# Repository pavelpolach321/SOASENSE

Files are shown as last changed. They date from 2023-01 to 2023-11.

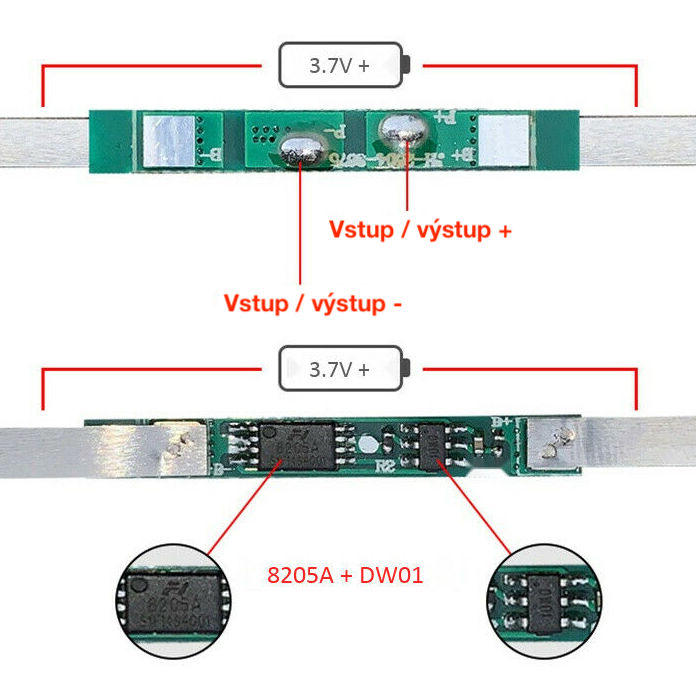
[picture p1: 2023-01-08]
Docs/bms-1s-3A-detail.jpg

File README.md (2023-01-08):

# About this repository:

The code is in the src/ folder

Mode of operation can be controlled with microswitches on the top board.

position  function           LEFT                     RIGHT     Comment
[8]       wifi credentials   setup or use old setup   erase     Implemented
[7]       connectivity       wifi                     lorawan   Not implemented yet
[6]       display            on                       off       Not implemented yet
[5]       reserved           [x]                      [x]       Not implemented yet
[4]       serial debug       on                       off       Not implemented yet
[3]       serial output      text                     json      Not implemented yet
[2]       reserved           [x]                      [x]       Not implemented yet
[1]       reserved           [x]                      [x]       Not implemented yet

# Connect the node

* Toggle the on/off switch down.
* Connect the power cable
* To erase/reset wifi credentials, put the swqitch n.8 to the right
* Toggle the on/off switch up, the board will start and display will show MAC address and AP details. Previously saved wifi cponnection is erased. Node is ready to connect.
* Put the switch n.8 to the left and reset/re-power the node
* Check accessible AP points with your mobile, search for SOASENSE_AP
* Connect with password "tacrnode"
* Page should appear, if not, gGo to 192.168.0.4, setup wifi credentials where you want node to be conected
* Node will restart itself and start sending data. You can see counter and other details on display.

# Firmware files

For provisioning use files in node_setup/ and keyfiles/ folders

During normal fw compilation, EEPROM mode should be "#define EEPROM_MODE         EEPROM_SHOW"

All sensor's related files are in a folder src/hardware'

To disable/enable/control sensor's behaviour', check setup.h file.

Most of the functional code of LMIC-node stays the same, we just introduced a few function calls to collect data, create payload and write results into debug. Function related to our fork are in hardware.cpp/.h

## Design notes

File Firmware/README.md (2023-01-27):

Currently, WIFI is used as a wireless protocol for transferring data.

Operating manual could be found here: https://github.com/pavelpolach321/SOASENSE/blob/master/README.md

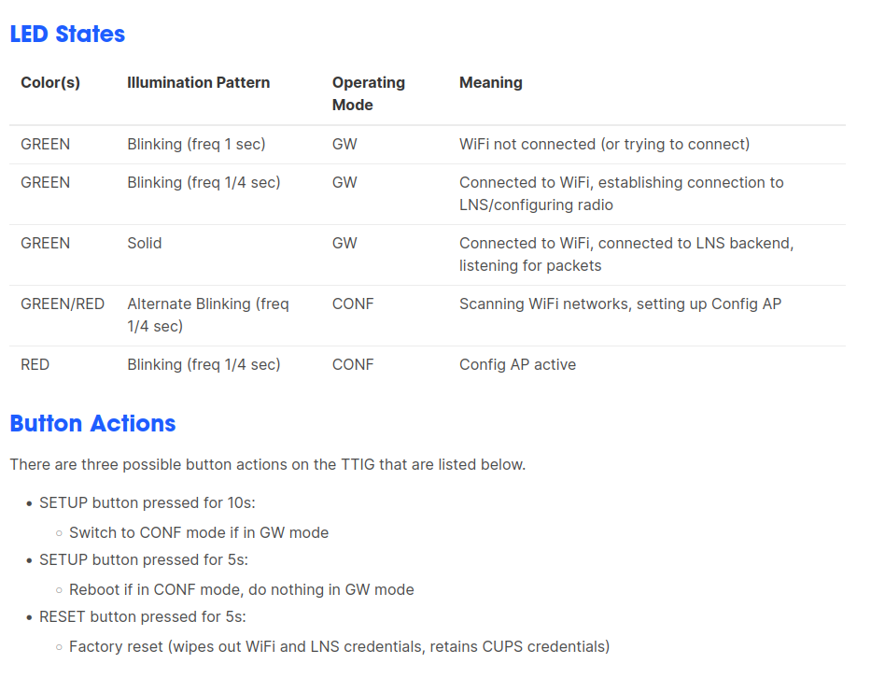
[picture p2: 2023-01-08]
Docs/gateway.png

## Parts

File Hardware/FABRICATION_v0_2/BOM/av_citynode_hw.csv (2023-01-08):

Id | Designator | Package | Quantity | Designation | Supplier and ref
1 | R9,R11,R7,R8,R6 | R_0805_2012Metric | 5 | 100k
2 | H9,H5,H3,H4,H1,H2,H6 | MountingHole_4.3mm_M4 | 7 | MountingHole
3 | R17 | R_0805_2012Metric | 1 | R
4 | J10,J11,J1,J3,J17,J22,J7,J19,J2,J12,J24,J16,J18,J21,J6,J23,J14,J5,J9,J15 | PinSocket_1x10_P2.54mm_Vertical | 20 | Conn_01x10_Female
5 | U7 | SOIC-16_4.55x10.3mm_P1.27mm | 1 | PCF8574
6 | J4 | PinSocket_1x02_P2.54mm_Vertical | 1 | Batt_wire
7 | U13 | SPS30 | 1 | SPS30
8 | U6 | PPAK | 1 | 59151
9 | C4,C1,C24,C8 | C_0805_2012Metric_Pad1.18x1.45mm_HandSolder | 4 | 100n
10 | C13,C11 | C_0805_2012Metric | 2 | 22u
11 | R13,R14,R4,R5,R1,R2,R15,R12,R16,R3 | R_0805_2012Metric | 10 | 10k
12 | J28,J27 | PinSocket_1x01_P2.54mm_Vertical | 2 | Conn_01x01_Female
13 | R10 | R_0805_2012Metric | 1 | 220k
14 | C3 | C_0805_2012Metric_Pad1.18x1.45mm_HandSolder | 1 | 1uF
15 | U9 | LILYGO-LORAWAN | 1 | LILYGO-lorawan
16 | U5 | STEP_UP | 1 | DC-DC
17 | H8,H7 | opc-n3-hole | 2 | MountingHole
18 | C19,C7,C21,C17 | C_0805_2012Metric | 4 | 10n
19 | C12,C22,C10,C18,C16,C14 | C_0805_2012Metric | 6 | 100n
20 | JP8,JP18,JP17,JP9 | SolderJumper-3_P1.3mm_Bridged12_Pad1.0x1.5mm | 4 | SolderJumper_3_Bridged12
21 | JP6,JP5,JP10,JP12,JP4,JP7,JP15 | SolderJumper-2_P1.3mm_Bridged_RoundedPad1.0x1.5mm | 7 | Close
22 | U20,U3,U2,U1 | Sensor_module | 4 | Sensor_socket
23 | U4 | DC-DC | 1 | MPPT
24 | C5,C20 | CP_Radial_D5.0mm_P2.50mm | 2 | 220u
25 | SW3 | SW_PUSH_6mm | 1 | SW_DIP_x01
26 | JP11 | SolderJumper-2_P1.3mm_Bridged_RoundedPad1.0x1.5mm | 1 | SolderJumper_2_Open
27 | SW1 | SW_DIP_SPSTx08_Slide_6.7x21.88mm_W7.62mm_P2.54mm_LowProfile | 1 | SW_DIP_x08
28 | U22 | SOT-223 | 1 | TC1264-3v3
29 | C26,C9,C6,C2 | C_0805_2012Metric_Pad1.18x1.45mm_HandSolder | 4 | dnp
30 | BT1,BT2 | BatteryHolder_MPD_BH-18650-PC2 | 2 | Battery_Cell
31 | JP1 | SolderJumper-3_P1.3mm_Bridged12_RoundedPad1.0x1.5mm_NumberLabels | 1 | SolderJumper_3_Bridged12
32 | J26 | PinHeader_1x01_P2.54mm_Vertical | 1 | Conn_01x01_Female
33 | SW2 | Switch | 1 | SW_DPDT_x2
34 | U14 | NEO-6M-mod | 1 | NEO-6M
35 | J25 | PinSocket_1x04_P2.54mm_Vertical | 1 | Conn_01x04_Female
36 | U15 | SOT-223 | 1 | XC6203P352FR-G_
37 | JP3 | SolderJumper-2_P1.3mm_Bridged_Pad1.0x1.5mm | 1 | Close
38 | J8 | BarrelJack_Horizontal | 1 | Barrel_Jack_Switch
39 | JP2 | SolderJumper-2_P1.3mm_Open_RoundedPad1.0x1.5mm | 1 | SolderJumper_2_Open
40 | U23,U25,U24 | mp2315-module | 3 | step-down
41 | AFE3,AFE1,AFE4 | Alphasense_AFE_6pin-LEFT | 3 | Alphasense_AFE_6pin
42 | C15 | CP_Radial_D10.0mm_P3.50mm | 1 | 470u
43 | J13 | PinHeader_1x05_P2.54mm_Vertical | 1 | Conn_01x05_Female
44 | U12 | opc-n3_3holes | 1 | OPC_N3
45 | AFE2 | Alphasense_AFE_6pin-RIGHT | 1 | Alphasense_AFE_6pin
46 | U11,U8 | ADS1115-module | 2 | ADS1115_module
47 | JP16 | SolderJumper-2_P1.3mm_Bridged_RoundedPad1.0x1.5mm | 1 | close
48 | U21,U19 | DW01_protection | 2 | DW01_protection
49 | JP13,JP14 | SolderJumper-2_P1.3mm_Open_RoundedPad1.0x1.5mm | 2 | Open
50 | C23 | CP_Radial_D12.5mm_P5.00mm | 1 | 2200uF
51 | U10 | BME280-module | 1 | BME280_module
52 | J20 | PinHeader_1x06_P2.54mm_Vertical | 1 | Conn_01x06_Female

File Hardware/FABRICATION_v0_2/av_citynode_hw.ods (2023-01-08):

Id | Designator | Package | Quantity | Designation | Supplier and ref
1 | R9,R11,R7,R8,R6 | R_0805_2012Metric | 5 | 100k
2 | H9,H5,H3,H4,H1,H2,H6 | MountingHole_4.3mm_M4 | 7 | MountingHole
3 | R17 | R_0805_2012Metric | 1 | R
4 | J10,J11,J1,J3,J17,J22,J7,J19,J2,J12,J24,J16,J18,J21,J6,J23,J14,J5,J9,J15 | PinSocket_1x10_P2.54mm_Vertical | 20 | Conn_01x10_Female
5 | U7 | SOIC-16_4.55x10.3mm_P1.27mm | 1 | PCF8574 | https://cz.mouser.com/ProductDetail/NXP-Semiconductors/PCF8574T-3518?qs=LOCUfHb8d9srwcgHHpXqQw%3D%3D
6 | J4 | PinSocket_1x02_P2.54mm_Vertical | 1 | Batt_wire
7 | U13 | SPS30 | 1 | SPS30
8 | U6 | PPAK | 1 | 59151
9 | C4,C1,C24,C8 | C_0805_2012Metric_Pad1.18x1.45mm_HandSolder | 4 | 100n
10 | C13,C11 | C_0805_2012Metric | 2 | 22u
11 | R13,R14,R4,R5,R1,R2,R15,R12,R16,R3 | R_0805_2012Metric | 10 | 10k
12 | J28,J27 | PinSocket_1x01_P2.54mm_Vertical | 2 | Conn_01x01_Female
13 | R10 | R_0805_2012Metric | 1 | 220k
14 | C3 | C_0805_2012Metric_Pad1.18x1.45mm_HandSolder | 1 | 1uF
15 | U9 | LILYGO-LORAWAN | 1 | LILYGO-lorawan
16 | U5 | STEP_UP | 1 | DC-DC
17 | H8,H7 | opc-n3-hole | 2 | MountingHole
18 | C19,C7,C21,C17 | C_0805_2012Metric | 4 | 10n
19 | C12,C22,C10,C18,C16,C14 | C_0805_2012Metric | 6 | 100n
20 | JP8,JP18,JP17,JP9 | SolderJumper-3_P1.3mm_Bridged12_Pad1.0x1.5mm | 4 | SolderJumper_3_Bridged12
21 | JP6,JP5,JP10,JP12,JP4,JP7,JP15 | SolderJumper-2_P1.3mm_Bridged_RoundedPad1.0x1.5mm | 7 | Close
22 | U20,U3,U2,U1 | Sensor_module | 4 | Sensor_socket
23 | U4 | DC-DC | 1 | MPPT
24 | C5,C20 | CP_Radial_D5.0mm_P2.50mm | 2 | 220u
25 | SW3 | SW_PUSH_6mm | 1 | SW_DIP_x01 | https://www.gme.cz/tc-0109
26 | JP11 | SolderJumper-2_P1.3mm_Bridged_RoundedPad1.0x1.5mm | 1 | SolderJumper_2_Open
27 | SW1 | SW_DIP_SPSTx08_Slide_6.7x21.88mm_W7.62mm_P2.54mm_LowProfile | 1 | SW_DIP_x08 | https://cz.mouser.com/ProductDetail/Diptronics/NDI-08S-V?qs=MLItCLRbWszcDzTw3vqmsQ%3D%3D
28 | U22 | SOT-223 | 1 | TC1264-3v3 | https://cz.mouser.com/ProductDetail/Microchip-Technology-Atmel/TC1264-3.3VDBTR?qs=EkZBwCRGcSs72PT5fOeaFg%3D%3D
29 | C26,C9,C6,C2 | C_0805_2012Metric_Pad1.18x1.45mm_HandSolder | 4 | dnp
30 | BT1,BT2 | BatteryHolder_MPD_BH-18650-PC2 | 2 | Battery_Cell
31 | JP1 | SolderJumper-3_P1.3mm_Bridged12_RoundedPad1.0x1.5mm_NumberLabels | 1 | SolderJumper_3_Bridged12
32 | J26 | PinHeader_1x01_P2.54mm_Vertical | 1 | Conn_01x01_Female
33 | SW2 | Switch | 1 | SW_DPDT_x2 | https://www.gme.cz/p-knx2
34 | U14 | NEO-6M-mod | 1 | NEO-6M
35 | J25 | PinSocket_1x04_P2.54mm_Vertical | 1 | Conn_01x04_Female
36 | U15 | SOT-223 | 1 | XC6203P352FR-G_
37 | JP3 | SolderJumper-2_P1.3mm_Bridged_Pad1.0x1.5mm | 1 | Close
38 | J8 | BarrelJack_Horizontal | 1 | Barrel_Jack_Switch
39 | JP2 | SolderJumper-2_P1.3mm_Open_RoundedPad1.0x1.5mm | 1 | SolderJumper_2_Open
40 | U23,U25,U24 | mp2315-module | 3 | step-down | https://www.laskakit.cz/mikro-step-down-menic--nastavitelny/
41 | AFE3,AFE1,AFE4 | Alphasense_AFE_6pin-LEFT | 3 | Alphasense_AFE_6pin
42 | C15 | CP_Radial_D10.0mm_P3.50mm | 1 | 470u
43 | J13 | PinHeader_1x05_P2.54mm_Vertical | 1 | Conn_01x05_Female
44 | U12 | opc-n3_3holes | 1 | OPC_N3
45 | AFE2 | Alphasense_AFE_6pin-RIGHT | 1 | Alphasense_AFE_6pin
46 | U11,U8 | ADS1115-module | 2 | ADS1115_module
47 | JP16 | SolderJumper-2_P1.3mm_Bridged_RoundedPad1.0x1.5mm | 1 | close
48 | U21,U19 | DW01_protection | 2 | DW01_protection
49 | JP13,JP14 | SolderJumper-2_P1.3mm_Open_RoundedPad1.0x1.5mm | 2 | Open
50 | U10 | BME280-module | 1 | BME280_module
51 | J20 | PinHeader_1x06_P2.54mm_Vertical | 1 | Conn_01x06_Female
 | baterka |  |  |  | https://www.gme.cz/oloveny-akumulator-westinghouse-wa650-6v-5ah
 | adapter |  |  |  | https://www.gme.cz/napajeci-adapter-sitovy-9v-600ma-5-5-2-1mm-vigan
 | levnejsi board |  |  |  | https://www.laskakit.cz/mh-et-live-esp32-minikit--wemos-d1-mini-shield-kompatibilni/

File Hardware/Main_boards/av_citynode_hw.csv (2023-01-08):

Source: | /home/ia/Desktop/node/av_citynode_hw/av_citynode_hw.kicad_sch
Date: | Wed 26 Oct 2022 01:55:53 PM CEST
Tool: | Eeschema 6.0.7-f9a2dced07~116~ubuntu20.04.1
Generator: | /usr/share/kicad/plugins/bom_csv_grouped_by_value.py
Component Count: | 111
Individual Components:
Item | Qty | Reference(s) | Value | LibPart | Footprint | Datasheet
 |  | AFE1 | Alphasense_AFE_6pin | city_node:Alphasense_AFE_6pin | city_node_footprints:Alphasense_AFE_6pin-LEFT
 |  | AFE2 | Alphasense_AFE_6pin | city_node:Alphasense_AFE_6pin | city_node_footprints:Alphasense_AFE_6pin-RIGHT
 |  | BT1 | Battery_Cell | Device:Battery_Cell | Battery:BatteryHolder_MPD_BH-18650-PC2 | ~
 |  | BT2 | Battery_Cell | Device:Battery_Cell | Battery:BatteryHolder_MPD_BH-18650-PC2 | ~
 |  | C1 | C | Device:C | Capacitor_SMD:C_0805_2012Metric_Pad1.18x1.45mm_HandSolder | ~
 |  | C2 | C | Device:C | Capacitor_SMD:C_0805_2012Metric_Pad1.18x1.45mm_HandSolder | ~
 |  | C3 | 10n | Device:C | Capacitor_SMD:C_0805_2012Metric_Pad1.18x1.45mm_HandSolder | ~
 |  | C4 | C | Device:C | Capacitor_SMD:C_0805_2012Metric_Pad1.18x1.45mm_HandSolder | ~
 |  | C5 | 10n | Device:C | Capacitor_SMD:C_0805_2012Metric_Pad1.18x1.45mm_HandSolder | ~
 |  | C6 | C | Device:C | Capacitor_SMD:C_0805_2012Metric_Pad1.18x1.45mm_HandSolder | ~
 |  | C7 | 10n | Device:C | Capacitor_SMD:C_0805_2012Metric_Pad1.18x1.45mm_HandSolder | ~
 |  | C8 | C | Device:C | Capacitor_SMD:C_0805_2012Metric_Pad1.18x1.45mm_HandSolder | ~
 |  | C9 | C | Device:C | Capacitor_SMD:C_0805_2012Metric_Pad1.18x1.45mm_HandSolder | ~
 |  | C10 | C | Device:C | Capacitor_SMD:C_0805_2012Metric | ~
 |  | C11 | C | Device:C | Capacitor_SMD:C_0805_2012Metric | ~
 |  | C12 | C | Device:C | Capacitor_SMD:C_0805_2012Metric | ~
 |  | C13 | C | Device:C | Capacitor_SMD:C_0805_2012Metric | ~
 |  | C14 | 100n | Device:C | Capacitor_SMD:C_0805_2012Metric | ~
 |  | C15 | 470u | Device:C | Capacitor_THT:CP_Radial_D10.0mm_P3.50mm | ~
 |  | C16 | 100n | Device:C | Capacitor_SMD:C_0805_2012Metric | ~
 |  | C17 | 10n | Device:C | Capacitor_SMD:C_0805_2012Metric | ~
 |  | C18 | 100n | Device:C | Capacitor_SMD:C_0805_2012Metric | ~
 |  | C19 | 22u | Device:C | Capacitor_SMD:C_0805_2012Metric | ~
 |  | C20 | 470u | Device:C | Capacitor_THT:CP_Radial_D5.0mm_P2.50mm | ~
 |  | C21 | 10n | Device:C | Capacitor_SMD:C_0805_2012Metric | ~
 |  | C22 | 10n | Device:C | Capacitor_SMD:C_0805_2012Metric | ~
 |  | C23 | C | Device:C | Capacitor_SMD:C_0805_2012Metric_Pad1.18x1.45mm_HandSolder | ~
 |  | C24 | C | Device:C | Capacitor_SMD:C_0805_2012Metric_Pad1.18x1.45mm_HandSolder | ~
 |  | C25 | C | Device:C | Capacitor_SMD:C_0805_2012Metric_Pad1.18x1.45mm_HandSolder | ~
 |  | C26 | C | Device:C | Capacitor_SMD:C_0805_2012Metric_Pad1.18x1.45mm_HandSolder | ~
 |  | H1 | MountingHole | Mechanical:MountingHole | city_node_footprints:MountingHole_4.3mm_M4 | ~
 |  | H2 | MountingHole | Mechanical:MountingHole | city_node_footprints:MountingHole_4.3mm_M4 | ~
 |  | H3 | MountingHole | Mechanical:MountingHole | city_node_footprints:MountingHole_4.3mm_M4 | ~
 |  | H4 | MountingHole | Mechanical:MountingHole | city_node_footprints:MountingHole_4.3mm_M4 | ~
 |  | H5 | MountingHole | Mechanical:MountingHole | city_node_footprints:MountingHole_4.3mm_M4 | ~
 |  | H6 | MountingHole | Mechanical:MountingHole | city_node_footprints:MountingHole_4.3mm_M4 | ~
 |  | H7 | MountingHole | Mechanical:MountingHole | city_node_footprints:opc-n3-hole | ~
 |  | H8 | MountingHole | Mechanical:MountingHole | city_node_footprints:opc-n3-hole | ~
 |  | J1 | Conn_01x10_Female | Connector:Conn_01x10_Female | Connector_PinSocket_2.54mm:PinSocket_1x10_P2.54mm_Vertical | ~
 |  | J2 | Conn_01x10_Female | Connector:Conn_01x10_Female | Connector_PinSocket_2.54mm:PinSocket_1x10_P2.54mm_Vertical | ~
 |  | J3 | Conn_01x10_Female | Connector:Conn_01x10_Female | Connector_PinSocket_2.54mm:PinSocket_1x10_P2.54mm_Vertical | ~
 |  | J4 | Batt_wire | Connector:Conn_01x02_Female | Connector_PinSocket_2.54mm:PinSocket_1x02_P2.54mm_Vertical | ~
 |  | J5 | Conn_01x10_Female | Connector:Conn_01x10_Female | Connector_PinSocket_2.54mm:PinSocket_1x10_P2.54mm_Vertical | ~
 |  | J6 | Conn_01x10_Female | Connector:Conn_01x10_Female | Connector_PinSocket_2.54mm:PinSocket_1x10_P2.54mm_Vertical | ~
 |  | J7 | Conn_01x10_Female | Connector:Conn_01x10_Female | Connector_PinSocket_2.54mm:PinSocket_1x10_P2.54mm_Vertical | ~
 |  | J8 | Barrel_Jack_Switch | Connector:Barrel_Jack_Switch | Connector_BarrelJack:BarrelJack_Horizontal | ~
 |  | J9 | Conn_01x10_Female | Connector:Conn_01x10_Female | Connector_PinSocket_2.54mm:PinSocket_1x10_P2.54mm_Vertical | ~
 |  | J10 | Conn_01x10_Female | Connector:Conn_01x10_Female | Connector_PinSocket_2.54mm:PinSocket_1x10_P2.54mm_Vertical | ~
 |  | J11 | Conn_01x10_Female | Connector:Conn_01x10_Female | Connector_PinSocket_2.54mm:PinSocket_1x10_P2.54mm_Vertical | ~
 |  | J12 | Conn_01x10_Female | Connector:Conn_01x10_Female | Connector_PinSocket_2.54mm:PinSocket_1x10_P2.54mm_Vertical | ~
 |  | J13 | Conn_01x05_Female | Connector:Conn_01x05_Female | Connector_PinHeader_2.54mm:PinHeader_1x05_P2.54mm_Vertical | ~
 |  | J14 | Conn_01x10_Female | Connector:Conn_01x10_Female | Connector_PinSocket_2.54mm:PinSocket_1x10_P2.54mm_Vertical | ~
 |  | J15 | Conn_01x10_Female | Connector:Conn_01x10_Female | Connector_PinSocket_2.54mm:PinSocket_1x10_P2.54mm_Vertical | ~
 |  | J16 | Conn_01x10_Female | Connector:Conn_01x10_Female | Connector_PinSocket_2.54mm:PinSocket_1x10_P2.54mm_Vertical | ~
 |  | J17 | Conn_01x10_Female | Connector:Conn_01x10_Female | Connector_PinSocket_2.54mm:PinSocket_1x10_P2.54mm_Vertical | ~
 |  | J18 | Conn_01x10_Female | Connector:Conn_01x10_Female | Connector_PinSocket_2.54mm:PinSocket_1x10_P2.54mm_Vertical | ~
 |  | J19 | Conn_01x10_Female | Connector:Conn_01x10_Female | Connector_PinSocket_2.54mm:PinSocket_1x10_P2.54mm_Vertical | ~
 |  | J20 | Conn_01x06_Female | Connector:Conn_01x06_Female | Connector_PinHeader_2.54mm:PinHeader_1x06_P2.54mm_Vertical | ~
 |  | J21 | Conn_01x10_Female | Connector:Conn_01x10_Female | Connector_PinSocket_2.54mm:PinSocket_1x10_P2.54mm_Vertical | ~
 |  | J22 | Conn_01x10_Female | Connector:Conn_01x10_Female | Connector_PinSocket_2.54mm:PinSocket_1x10_P2.54mm_Vertical | ~
 |  | J23 | Conn_01x10_Female | Connector:Conn_01x10_Female | Connector_PinSocket_2.54mm:PinSocket_1x10_P2.54mm_Vertical | ~
 |  | J24 | Conn_01x10_Female | Connector:Conn_01x10_Female | Connector_PinSocket_2.54mm:PinSocket_1x10_P2.54mm_Vertical | ~
 |  | J25 | Conn_01x04_Female | Connector:Conn_01x04_Female | Connector_PinSocket_2.54mm:PinSocket_1x04_P2.54mm_Vertical | ~
 |  | JP1 | SolderJumper_2_Bridged | Jumper:SolderJumper_2_Bridged | Jumper:SolderJumper-2_P1.3mm_Bridged_Pad1.0x1.5mm | ~
 |  | JP2 | SolderJumper_2_Open | Jumper:SolderJumper_2_Open | Jumper:SolderJumper-2_P1.3mm_Open_RoundedPad1.0x1.5mm | ~
 |  | JP3 | SolderJumper_2_Open | Jumper:SolderJumper_2_Open | Jumper:SolderJumper-2_P1.3mm_Open_RoundedPad1.0x1.5mm | ~
 |  | JP4 | SolderJumper_2_Open | Jumper:SolderJumper_2_Open | Jumper:SolderJumper-2_P1.3mm_Open_RoundedPad1.0x1.5mm | ~
 |  | JP5 | SolderJumper_2_Open | Jumper:SolderJumper_2_Open | Jumper:SolderJumper-2_P1.3mm_Open_Pad1.0x1.5mm | ~
 |  | JP6 | SolderJumper_2_Open | Jumper:SolderJumper_2_Open | Jumper:SolderJumper-2_P1.3mm_Open_RoundedPad1.0x1.5mm | ~
 |  | JP7 | SolderJumper_2_Bridged | Jumper:SolderJumper_2_Bridged | Jumper:SolderJumper-2_P1.3mm_Open_TrianglePad1.0x1.5mm | ~
 |  | JP8 | SolderJumper_2_Bridged | Jumper:SolderJumper_2_Bridged | Jumper:SolderJumper-2_P1.3mm_Open_TrianglePad1.0x1.5mm | ~
 |  | JP9 | SolderJumper_2_Bridged | Jumper:SolderJumper_2_Bridged | Jumper:SolderJumper-2_P1.3mm_Open_TrianglePad1.0x1.5mm | ~
 |  | JP10 | SolderJumper_2_Open | Jumper:SolderJumper_2_Open | Jumper:SolderJumper-2_P1.3mm_Open_RoundedPad1.0x1.5mm | ~
 |  | JP11 | SolderJumper_2_Open | Jumper:SolderJumper_2_Open | Jumper:SolderJumper-2_P1.3mm_Open_RoundedPad1.0x1.5mm | ~
 |  | JP12 | SolderJumper_2_Open | Jumper:SolderJumper_2_Open | Jumper:SolderJumper-2_P1.3mm_Open_RoundedPad1.0x1.5mm | ~
 |  | Q1 | Si2319CDS | Transistor_FET:Si2319CDS | Package_TO_SOT_SMD:SOT-23 | http://www.vishay.com/docs/66709/si2319cd.pdf
 |  | R1 | 100k | Device:R | Resistor_SMD:R_0805_2012Metric_Pad1.20x1.40mm_HandSolder | ~
 |  | R2 | 100k | Device:R | Resistor_SMD:R_0805_2012Metric_Pad1.20x1.40mm_HandSolder | ~
 |  | R3 | 100k | Device:R | Resistor_SMD:R_0805_2012Metric_Pad1.20x1.40mm_HandSolder | ~
 |  | R4 | R | Device:R | Resistor_SMD:R_0805_2012Metric | ~
 |  | R5 | R | Device:R | Resistor_SMD:R_0805_2012Metric | ~
 |  | R6 | 100k | Device:R | Resistor_SMD:R_0805_2012Metric | ~
 |  | R7 | 100k | Device:R | Resistor_SMD:R_0805_2012Metric | ~
 |  | R8 | 100k | Device:R | Resistor_SMD:R_0805_2012Metric | ~
 |  | R9 | 100k | Device:R | Resistor_SMD:R_0805_2012Metric | ~
 |  | R10 | 100k | Device:R | Resistor_SMD:R_0805_2012Metric | ~
 |  | R11 | 100k | Device:R | Resistor_SMD:R_0805_2012Metric | ~
 |  | R12 | 10k | Device:R | Resistor_SMD:R_0805_2012Metric | ~
 |  | R13 | 10k | Device:R | Resistor_SMD:R_0805_2012Metric | ~
 |  | SW1 | SW_DIP_x03 | Switch:SW_DIP_x03 | Package_DIP:DIP-6_W7.62mm | ~
 |  | SW2 | SW_SPDT | Switch:SW_SPDT | Button_Switch_THT:SW_Slide_1P2T_CK_OS102011MS2Q | ~
 |  | U1 | Sensor_socket | :Sensor_socket_1 | city_node_footprints:Sensor_module
 |  | U2 | Sensor_socket | :Sensor_socket_2 | city_node_footprints:Sensor_module
 |  | U3 | Sensor_socket | city_node:Sensor_socket | city_node_footprints:Sensor_module
 |  | U4 | MPPT | city_node:MPPT | city_node_footprints:DC-DC
 |  | U5 | DC-DC | city_node:DC-DC | city_node_footprints:STEP_UP
 |  | U6 | 59151 | city_node:59151 | Package_TO_SOT_SMD:TO-263-5_TabPin3
 |  | U7 | LD1117S50TR_SOT223 | Regulator_Linear:LD1117S50TR_SOT223 | Package_TO_SOT_SMD:SOT-223-3_TabPin2 | http://www.st.com/st-web-ui/static/active/en/resource/technical/document/datasheet/CD00000544.pdf
 |  | U8 | LF50_TO220 | Regulator_Linear:LF50_TO220 | Package_TO_SOT_THT:TO-220-3_Vertical | http://www.st.com/content/ccc/resource/technical/document/datasheet/c4/0e/7e/2a/be/bc/4c/bd/CD00000546.pdf/files/CD00000546.pdf/jcr:content/translations/en.CD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
 |  | U9 | LILYGO-lorawan | city_node:LILYGO-lorawan | city_node_footprints:LILYGO-LORAWAN
 |  | U10 | BME280_module | city_node:BME280_module | city_node_footprints:BME280-module
 |  | U11 | ADS1115_module | city_node:ADS1115_module | city_node_footprints:ADS1115-module
 |  | U12 | OPC_N3 | city_node:OPC_N3 | city_node_footprints:opc-n3
 |  | U13 | SPS30 | city_node:SPS30 | city_node_footprints:SPS30
 |  | U14 | NEO-6M | city_node:NEO-6M | city_node_footprints:NEO-6M-mod
 |  | U15 | XC6203P352FR-G_ | city_node:XC6203P352FR-G_ | Package_TO_SOT_SMD:SOT-223
 |  | U16 | REVISION | city_node:REVISION | city_node_footprints:REVISION
 |  | U17 | REVISION | city_node:REVISION | city_node_footprints:REVISION
 |  | U18 | REVISION | city_node:REVISION | city_node_footprints:REVISION
 |  | U19 | Sensor_socket | city_node:Sensor_socket | city_node_footprints:Sensor_module
 |  | U20 | Sensor_socket | city_node:Sensor_socket | city_node_footprints:Sensor_module
Collated Components:
Item | Qty | Reference(s) | Value | LibPart | Footprint | Datasheet
1 | 1 | AFE1 | Alphasense_AFE_6pin | city_node:Alphasense_AFE_6pin | city_node_footprints:Alphasense_AFE_6pin-LEFT
2 | 1 | AFE2 | Alphasense_AFE_6pin | city_node:Alphasense_AFE_6pin | city_node_footprints:Alphasense_AFE_6pin-RIGHT
3 | 2 | BT1, BT2 | Battery_Cell | Device:Battery_Cell | Battery:BatteryHolder_MPD_BH-18650-PC2 | ~
4 | 10 | C1, C2, C4, C6, C8, C9, C23, C24, C25, C26 | C | Device:C | Capacitor_SMD:C_0805_2012Metric_Pad1.18x1.45mm_HandSolder | ~
5 | 3 | C3, C5, C7 | 10n | Device:C | Capacitor_SMD:C_0805_2012Metric_Pad1.18x1.45mm_HandSolder | ~
6 | 4 | C10, C11, C12, C13 | C | Device:C | Capacitor_SMD:C_0805_2012Metric | ~
7 | 3 | C14, C16, C18 | 100n | Device:C | Capacitor_SMD:C_0805_2012Metric | ~
8 | 1 | C15 | 470u | Device:C | Capacitor_THT:CP_Radial_D10.0mm_P3.50mm | ~
9 | 3 | C17, C21, C22 | 10n | Device:C | Capacitor_SMD:C_0805_2012Metric | ~
10 | 1 | C19 | 22u | Device:C | Capacitor_SMD:C_0805_2012Metric | ~
11 | 1 | C20 | 470u | Device:C | Capacitor_THT:CP_Radial_D5.0mm_P2.50mm | ~
12 | 6 | H1, H2, H3, H4, H5, H6 | MountingHole | Mechanical:MountingHole | city_node_footprints:MountingHole_4.3mm_M4 | ~
13 | 2 | H7, H8 | MountingHole | Mechanical:MountingHole | city_node_footprints:opc-n3-hole | ~
14 | 20 | J1, J2, J3, J5, J6, J7, J9, J10, J11, J12, J14, J15, J16, J17, J18, J19, J21, J22, J23, J24 | Conn_01x10_Female | Connector:Conn_01x10_Female | Connector_PinSocket_2.54mm:PinSocket_1x10_P2.54mm_Vertical | ~
15 | 1 | J4 | Batt_wire | Connector:Conn_01x02_Female | Connector_PinSocket_2.54mm:PinSocket_1x02_P2.54mm_Vertical | ~
16 | 1 | J8 | Barrel_Jack_Switch | Connector:Barrel_Jack_Switch | Connector_BarrelJack:BarrelJack_Horizontal | ~
17 | 1 | J13 | Conn_01x05_Female | Connector:Conn_01x05_Female | Connector_PinHeader_2.54mm:PinHeader_1x05_P2.54mm_Vertical | ~
18 | 1 | J20 | Conn_01x06_Female | Connector:Conn_01x06_Female | Connector_PinHeader_2.54mm:PinHeader_1x06_P2.54mm_Vertical | ~
19 | 1 | J25 | Conn_01x04_Female | Connector:Conn_01x04_Female | Connector_PinSocket_2.54mm:PinSocket_1x04_P2.54mm_Vertical | ~
20 | 1 | JP1 | SolderJumper_2_Bridged | Jumper:SolderJumper_2_Bridged | Jumper:SolderJumper-2_P1.3mm_Bridged_Pad1.0x1.5mm | ~
21 | 7 | JP2, JP3, JP4, JP6, JP10, JP11, JP12 | SolderJumper_2_Open | Jumper:SolderJumper_2_Open | Jumper:SolderJumper-2_P1.3mm_Open_RoundedPad1.0x1.5mm | ~
22 | 1 | JP5 | SolderJumper_2_Open | Jumper:SolderJumper_2_Open | Jumper:SolderJumper-2_P1.3mm_Open_Pad1.0x1.5mm | ~
23 | 3 | JP7, JP8, JP9 | SolderJumper_2_Bridged | Jumper:SolderJumper_2_Bridged | Jumper:SolderJumper-2_P1.3mm_Open_TrianglePad1.0x1.5mm | ~
24 | 1 | Q1 | Si2319CDS | Transistor_FET:Si2319CDS | Package_TO_SOT_SMD:SOT-23 | http://www.vishay.com/docs/66709/si2319cd.pdf
25 | 3 | R1, R2, R3 | 100k | Device:R | Resistor_SMD:R_0805_2012Metric_Pad1.20x1.40mm_HandSolder | ~
26 | 2 | R4, R5 | R | Device:R | Resistor_SMD:R_0805_2012Metric | ~
27 | 6 | R6, R7, R8, R9, R10, R11 | 100k | Device:R | Resistor_SMD:R_0805_2012Metric | ~
28 | 2 | R12, R13 | 10k | Device:R | Resistor_SMD:R_0805_2012Metric | ~
29 | 1 | SW1 | SW_DIP_x03 | Switch:SW_DIP_x03 | Package_DIP:DIP-6_W7.62mm | ~
30 | 1 | SW2 | SW_SPDT | Switch:SW_SPDT | Button_Switch_THT:SW_Slide_1P2T_CK_OS102011MS2Q | ~
31 | 1 | U1 | Sensor_socket | :Sensor_socket_1 | city_node_footprints:Sensor_module
32 | 1 | U2 | Sensor_socket | :Sensor_socket_2 | city_node_footprints:Sensor_module
33 | 3 | U3, U19, U20 | Sensor_socket | city_node:Sensor_socket | city_node_footprints:Sensor_module
34 | 1 | U4 | MPPT | city_node:MPPT | city_node_footprints:DC-DC
35 | 1 | U5 | DC-DC | city_node:DC-DC | city_node_footprints:STEP_UP
36 | 1 | U6 | 59151 | city_node:59151 | Package_TO_SOT_SMD:TO-263-5_TabPin3
37 | 1 | U7 | LD1117S50TR_SOT223 | Regulator_Linear:LD1117S50TR_SOT223 | Package_TO_SOT_SMD:SOT-223-3_TabPin2 | http://www.st.com/st-web-ui/static/active/en/resource/technical/document/datasheet/CD00000544.pdf
38 | 1 | U8 | LF50_TO220 | Regulator_Linear:LF50_TO220 | Package_TO_SOT_THT:TO-220-3_Vertical | http://www.st.com/content/ccc/resource/technical/document/datasheet/c4/0e/7e/2a/be/bc/4c/bd/CD00000546.pdf/files/CD00000546.pdf/jcr:content/translations/en.CD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
39 | 1 | U9 | LILYGO-lorawan | city_node:LILYGO-lorawan | city_node_footprints:LILYGO-LORAWAN
40 | 1 | U10 | BME280_module | city_node:BME280_module | city_node_footprints:BME280-module
41 | 1 | U11 | ADS1115_module | city_node:ADS1115_module | city_node_footprints:ADS1115-module
42 | 1 | U12 | OPC_N3 | city_node:OPC_N3 | city_node_footprints:opc-n3
43 | 1 | U13 | SPS30 | city_node:SPS30 | city_node_footprints:SPS30
44 | 1 | U14 | NEO-6M | city_node:NEO-6M | city_node_footprints:NEO-6M-mod
45 | 1 | U15 | XC6203P352FR-G_ | city_node:XC6203P352FR-G_ | Package_TO_SOT_SMD:SOT-223
46 | 3 | U16, U17, U18 | REVISION | city_node:REVISION | city_node_footprints:REVISION

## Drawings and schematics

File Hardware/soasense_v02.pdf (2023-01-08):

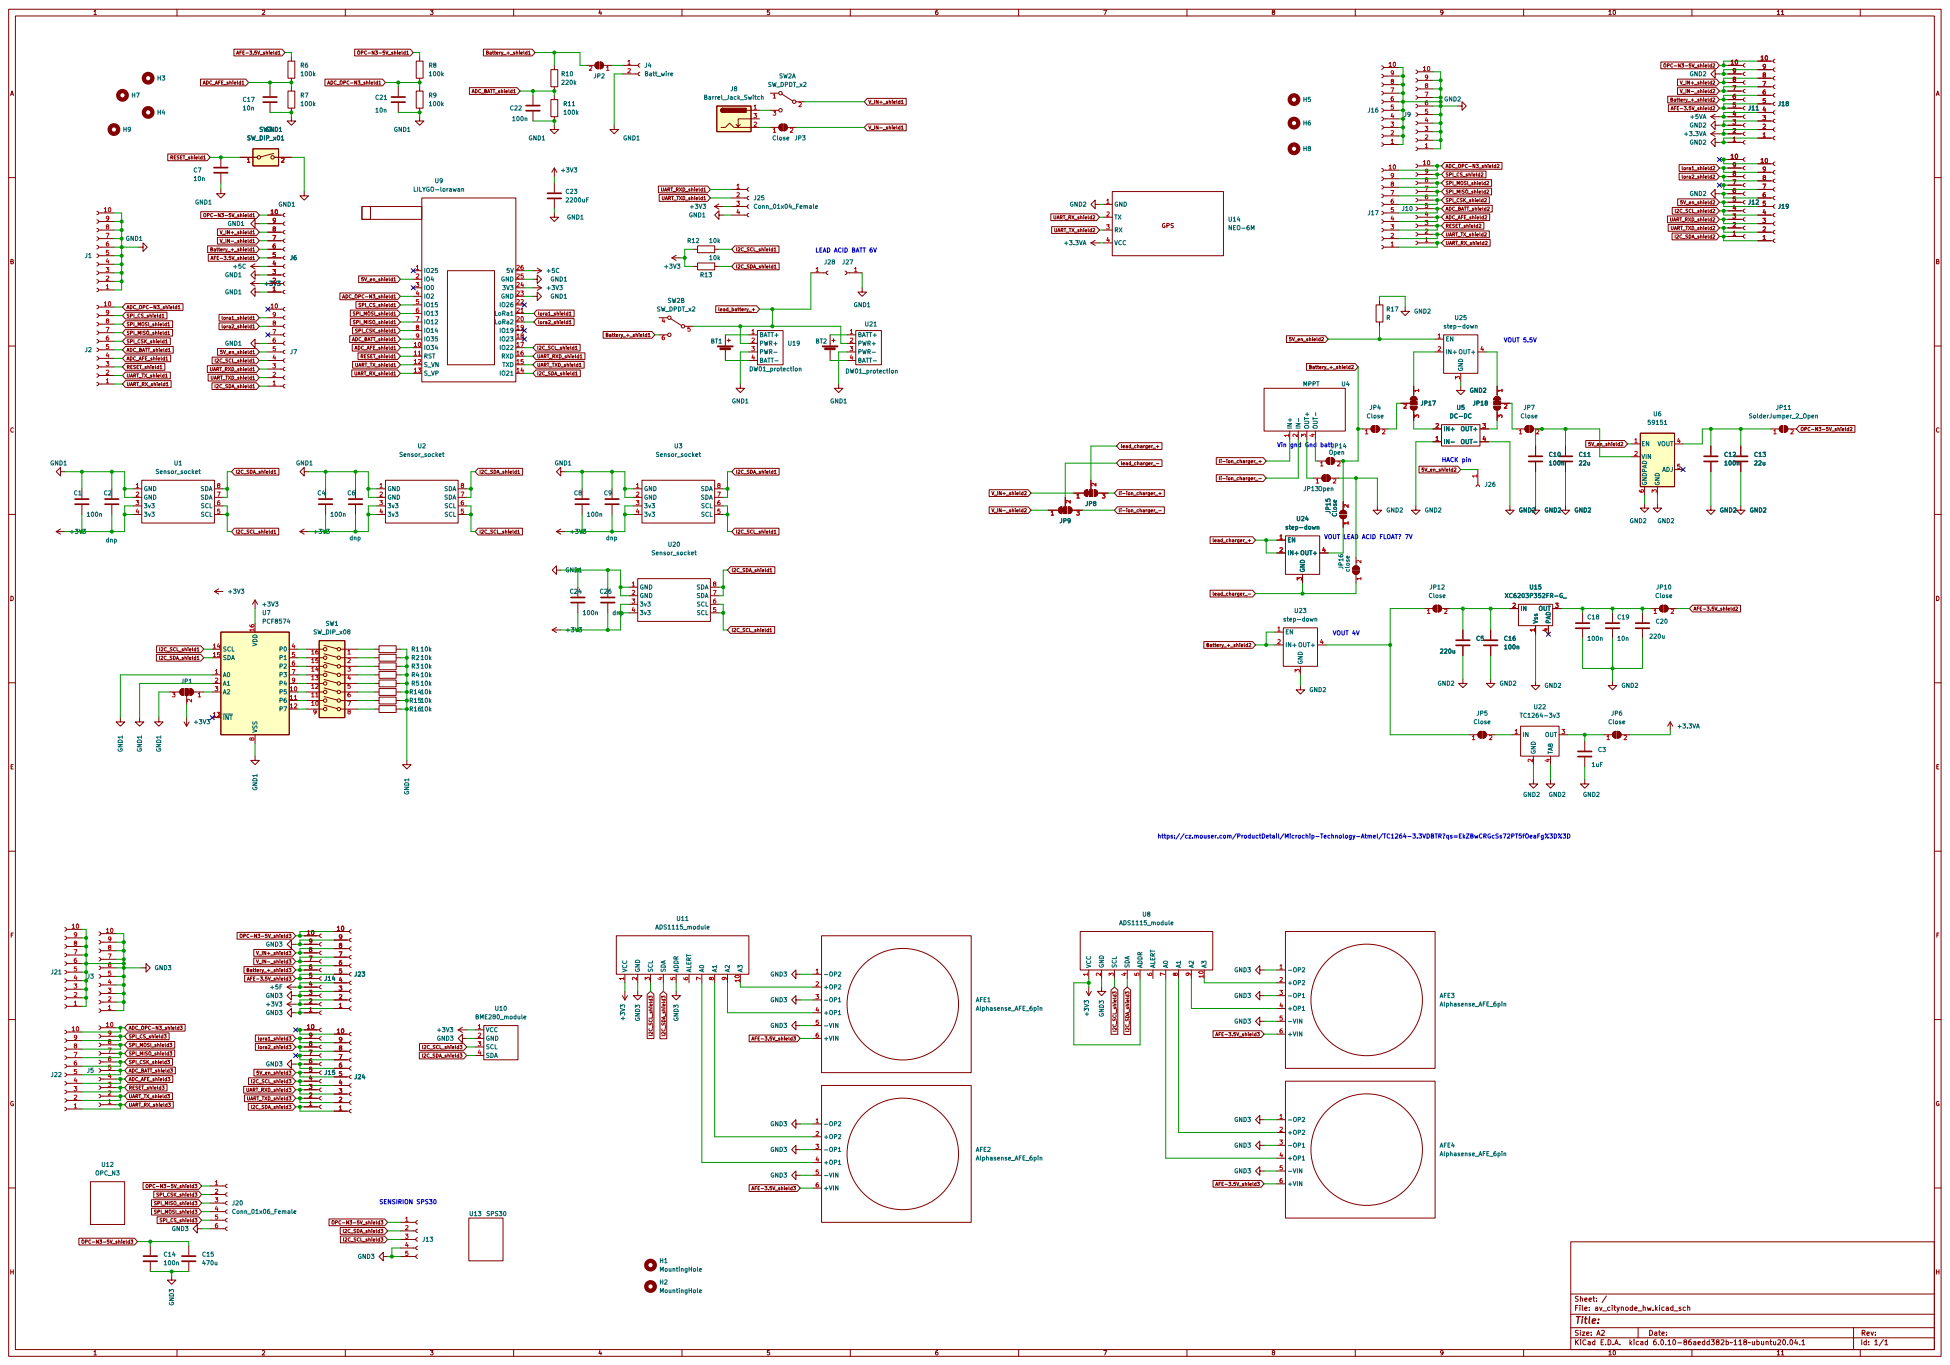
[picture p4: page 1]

3 OUT- 4 MPPT U4 GND 1 GND 2

Vin gnd Gnd batt

VOUT LEAD ACID FLOAT? 7V

https://cz.mouser.com/ProductDetail/Microchip-Technology-Atmel/TC1264-3.3VDBTR?qs=EkZBwCRGcSs72PT5fOeaFg%3D%3D

9 U11 ADS1115_module GND3 VCC 1 GND 2 SCL 3 SDA 4 U10 BME280_module

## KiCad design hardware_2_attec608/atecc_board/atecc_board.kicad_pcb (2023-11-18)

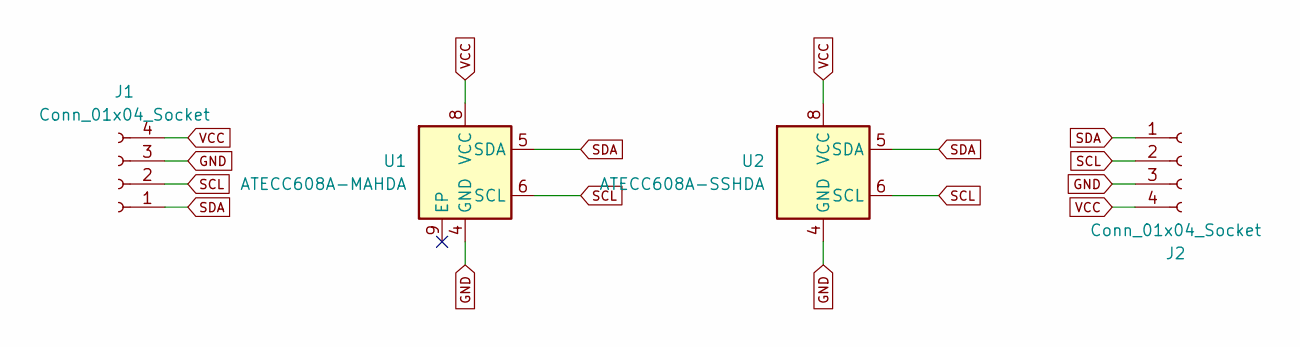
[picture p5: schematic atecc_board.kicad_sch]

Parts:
J1, J2: Conn_01x04_Socket; PinHeader_1x04_P2.54mm_Vertical
U1: ATECC608A-MAHDA; DFN-8-1EP_3x2mm_P0.5mm_EP1.3x1.5mm
U2: ATECC608A-SSHDA; SOIC-8_3.9x4.9mm_P1.27mm

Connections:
GND: J1.3, J2.3, U1.4 (GND), U2.4 (GND)
SCL: J1.2, J2.2, U1.6 (SCL), U2.6 (SCL)
SDA: J1.1, J2.1, U1.5 (SDA), U2.5 (SDA)
VCC: J1.4, J2.4, U1.8 (VCC), U2.8 (VCC)

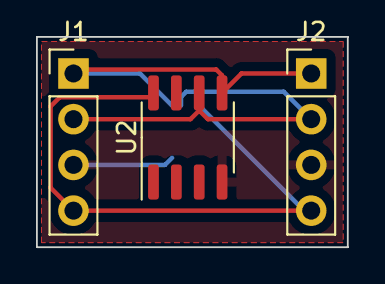
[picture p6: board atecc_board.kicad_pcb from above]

Board: 2 copper layers, 17.3 x 11.7 mm, 4 parts (1 on the bottom side), 4 nets.

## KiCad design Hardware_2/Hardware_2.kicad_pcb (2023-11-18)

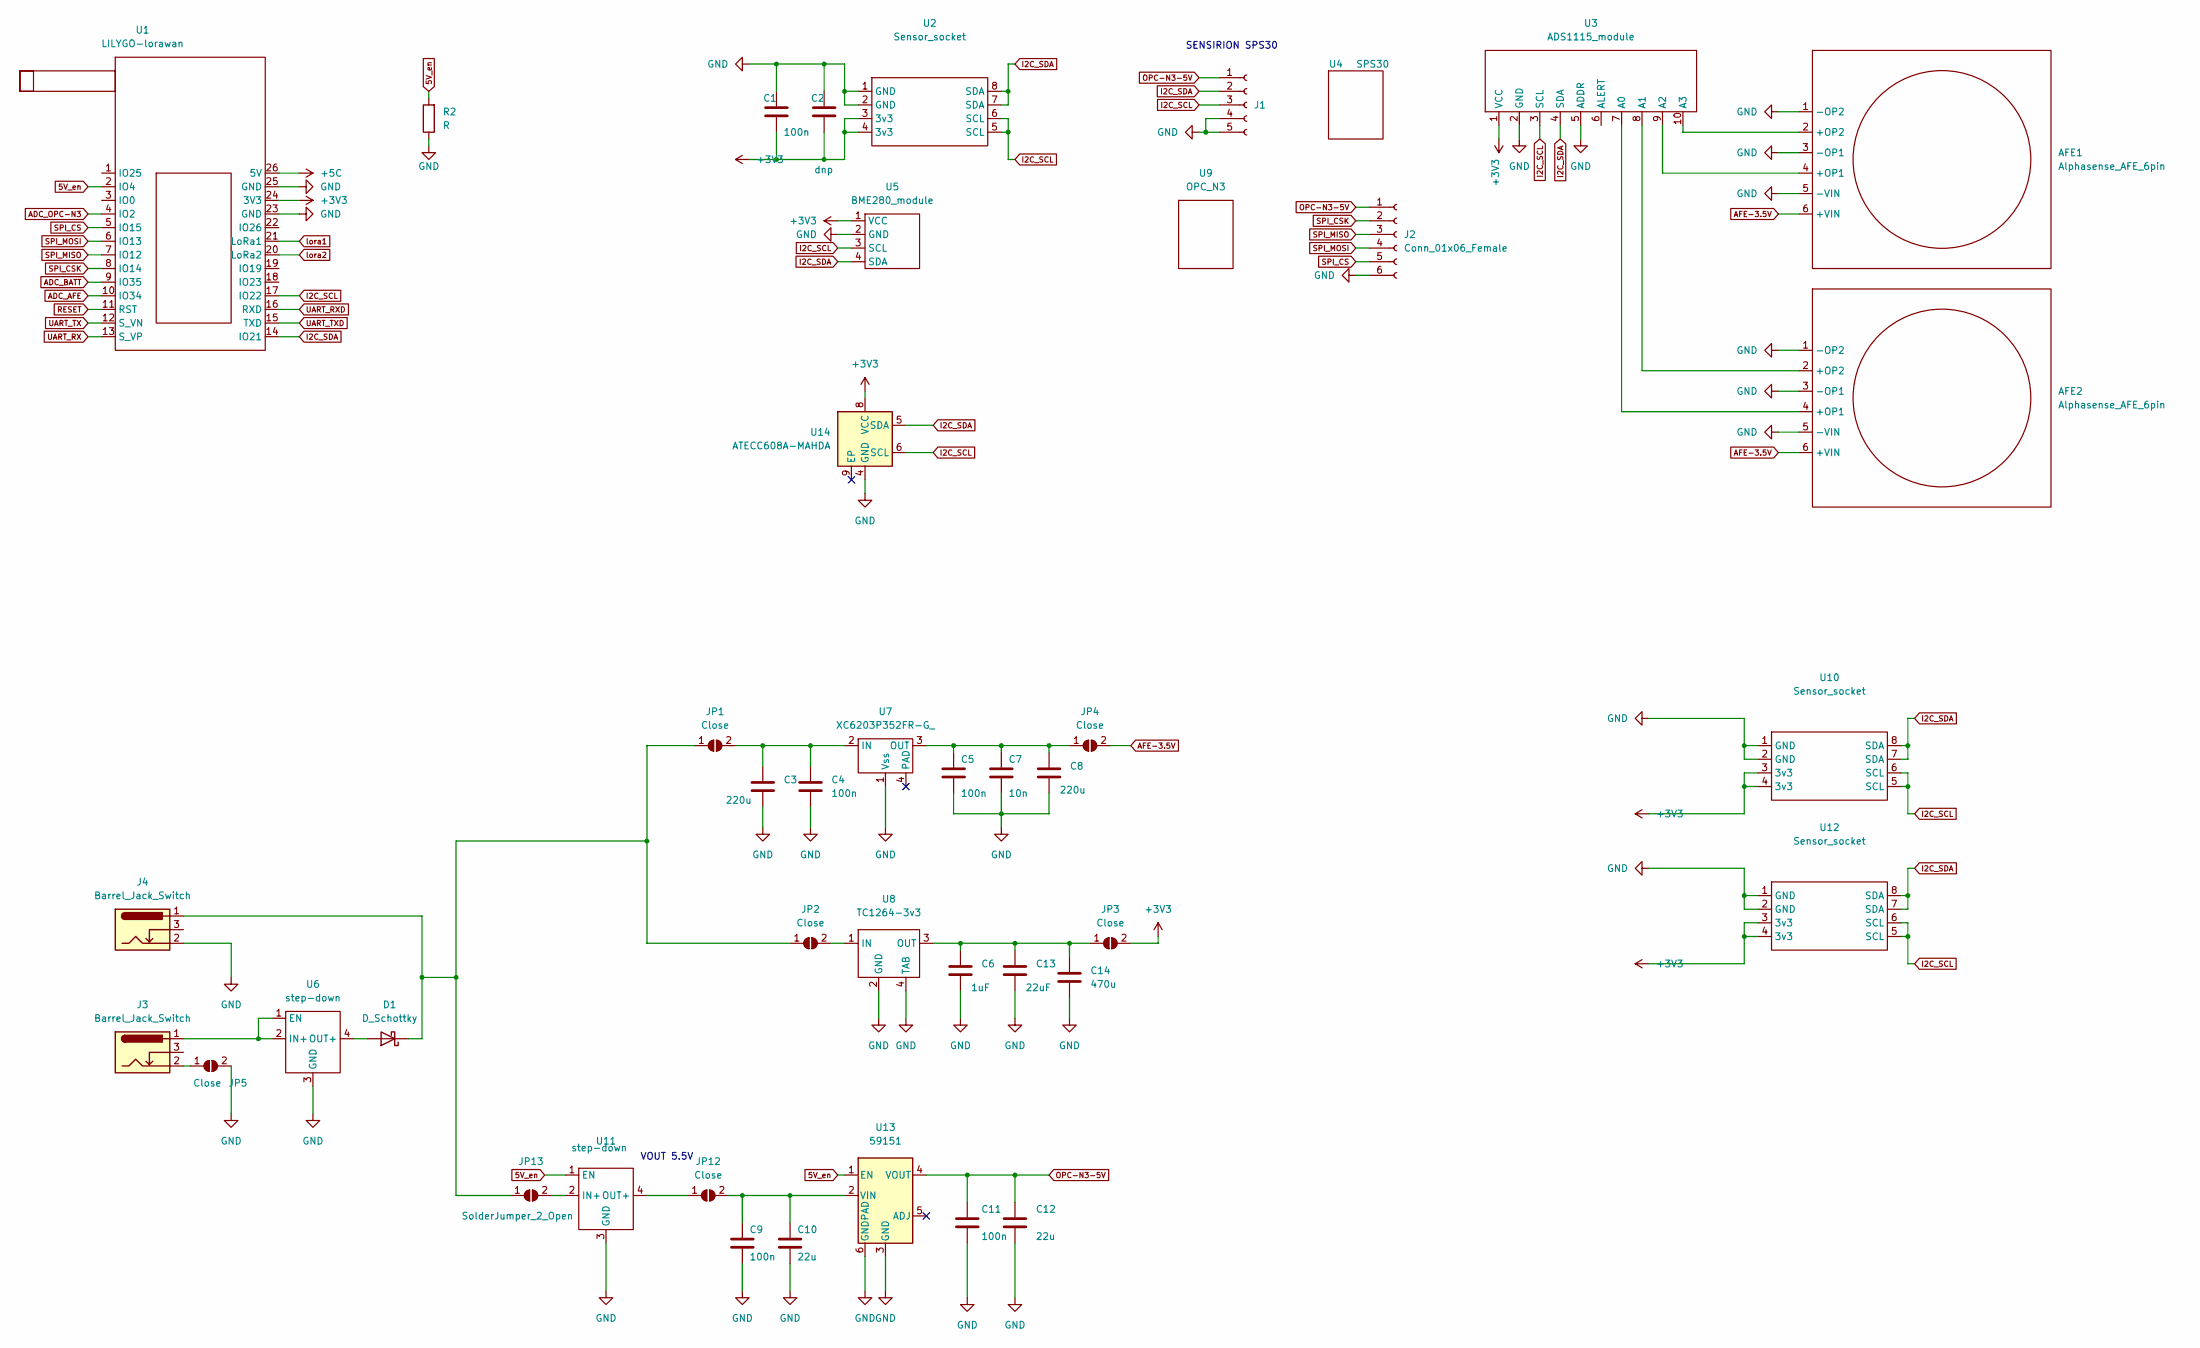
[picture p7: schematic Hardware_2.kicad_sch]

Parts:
AFE1: Alphasense_AFE_6pin; Alphasense_AFE_6pin-LEFT
AFE2: Alphasense_AFE_6pin; Alphasense_AFE_6pin-RIGHT
C1: 100n; C_0805_2012Metric_Pad1.18x1.45mm_HandSolder
C2: dnp; C_0805_2012Metric_Pad1.18x1.45mm_HandSolder
C3, C8: 220u; CP_Radial_D5.0mm_P2.50mm
C4, C5, C9, C11: 100n; C_0805_2012Metric
C6: 1uF; C_0805_2012Metric_Pad1.18x1.45mm_HandSolder
C7: 10n; C_0805_2012Metric
C10, C12: 22u; C_0805_2012Metric
C13: 22uF; C_0805_2012Metric_Pad1.18x1.45mm_HandSolder
C14: 470u; CP_Radial_D10.0mm_P3.50mm
D1: D_Schottky; D_2114_3652Metric_Pad1.85x3.75mm_HandSolder
J1: Conn_01x05_Female; PinHeader_1x05_P2.54mm_Vertical
J2: Conn_01x06_Female; PinHeader_1x06_P2.54mm_Vertical
J3, J4: Barrel_Jack_Switch; BarrelJack_Horizontal
JP1, JP2, JP3, JP4, JP12: Close; SolderJumper-2_P1.3mm_Bridged_RoundedPad1.0x1.5mm
JP5: Close; SolderJumper-2_P1.3mm_Bridged_Pad1.0x1.5mm
JP13: SolderJumper_2_Open; SolderJumper-2_P1.3mm_Bridged_RoundedPad1.0x1.5mm
R2: R; R_0805_2012Metric
U1: LILYGO-lorawan; LILYGO-LORAWAN
U2, U10, U12: Sensor_socket; Sensor_module
U3: ADS1115_module; ADS1115-module
U4: SPS30
U5: BME280_module; BME280-module
U6, U11: step-down; mp2315-module
U7: XC6203P352FR-G_; SOT-223
U8: TC1264-3v3; SOT-223
U9: OPC_N3; opc-n3_3holes
U13: 59151; PPAK
U14: ATECC608A-MAHDA; DFN-8-1EP_3x2mm_P0.5mm_EP1.3x1.5mm

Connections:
5V_en: R2.2, U1.2 (IO4), U11.1 (EN), U13.1 (EN)
+3V3: C1.2, C2.2, JP3.2 (B), U1.24 (3V3), U2.3 (3v3), U2.4 (3v3), U3.1 (VCC), U5.1 (VCC), U10.3 (3v3), U10.4 (3v3), U12.3 (3v3), U12.4 (3v3), U14.8 (VCC)
+5C: U1.26 (5V)
ADC_AFE: U1.10 (IO34)
ADC_BATT: U1.9 (IO35)
ADC_OPC-N3: U1.4 (IO2)
AFE-3.5V: AFE1.6 (+VIN), AFE2.6 (+VIN), JP4.2 (B)
GND: AFE1.1 (-OP2), AFE1.3 (-OP1), AFE1.5 (-VIN), AFE2.1 (-OP2), AFE2.3 (-OP1), AFE2.5 (-VIN), C1.1, C2.1, C3.2, C4.2, C5.2, C6.2, C7.2, C8.2, C9.2, C10.2, C11.2, C12.2, C13.2, C14.2, J1.4, J1.5, J2.6, J4.2, JP5.2 (B), R2.1, U1.23 (GND), U1.25 (GND), U2.1 (GND), U2.2 (GND), U3.2 (GND), U3.5 (ADDR), U5.2 (GND), U6.3 (GND), U7.1 (Vss), U8.2 (GND), U8.4 (TAB), U10.1 (GND), U10.2 (GND), U11.3 (GND), U12.1 (GND), U12.2 (GND), U13.3 (GND), U13.6 (GNDPAD), U14.4 (GND)
I2C_SCL: J1.3, U1.17 (IO22), U2.5 (SCL), U2.6 (SCL), U3.3 (SCL), U5.3 (SCL), U10.5 (SCL), U10.6 (SCL), U12.5 (SCL), U12.6 (SCL), U14.6 (SCL)
I2C_SDA: J1.2, U1.14 (IO21), U2.7 (SDA), U2.8 (SDA), U3.4 (SDA), U5.4 (SDA), U10.7 (SDA), U10.8 (SDA), U12.7 (SDA), U12.8 (SDA), U14.5 (SDA)
unnamed: AFE1.4 (+OP1), U3.9 (A2)
unnamed: AFE1.2 (+OP2), U3.10 (A3)
unnamed: AFE2.4 (+OP1), U3.7 (A0)
unnamed: AFE2.2 (+OP2), U3.8 (A1)
unnamed: D1.2 (A), U6.4 (OUT+)
unnamed: D1.1 (K), J4.1, JP1.1 (A), JP2.1 (A), JP13.1 (A)
unnamed: C3.1, C4.1, JP1.2 (B), U7.2 (IN)
unnamed: JP2.2 (B), U8.1 (IN)
unnamed: C6.1, C13.1, C14.1, JP3.1 (A), U8.3 (OUT)
unnamed: C5.1, C7.1, C8.1, JP4.1 (A), U7.3 (OUT)
unnamed: J3.2, JP5.1 (A)
unnamed: JP12.1 (A), U11.4 (OUT+)
unnamed: C9.1, C10.1, JP12.2 (B), U13.2 (VIN)
unnamed: JP13.2 (B), U11.2 (IN+)
unnamed: J3.1, U6.1 (EN), U6.2 (IN+)
OPC-N3-5V: C11.1, C12.1, J1.1, J2.1, U13.4 (VOUT)
RESET: U1.11 (RST)
SPI_CS: J2.5, U1.5 (IO15)
SPI_CSK: J2.2, U1.8 (IO14)
SPI_MISO: J2.3, U1.7 (IO12)
SPI_MOSI: J2.4, U1.6 (IO13)
UART_RX: U1.13 (S_VP)
UART_RXD: U1.16 (RXD)
UART_TX: U1.12 (S_VN)
UART_TXD: U1.15 (TXD)
lora1: U1.21 (LoRa1)
lora2: U1.20 (LoRa2)

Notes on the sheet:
VOUT 5.5V
SENSIRION SPS30

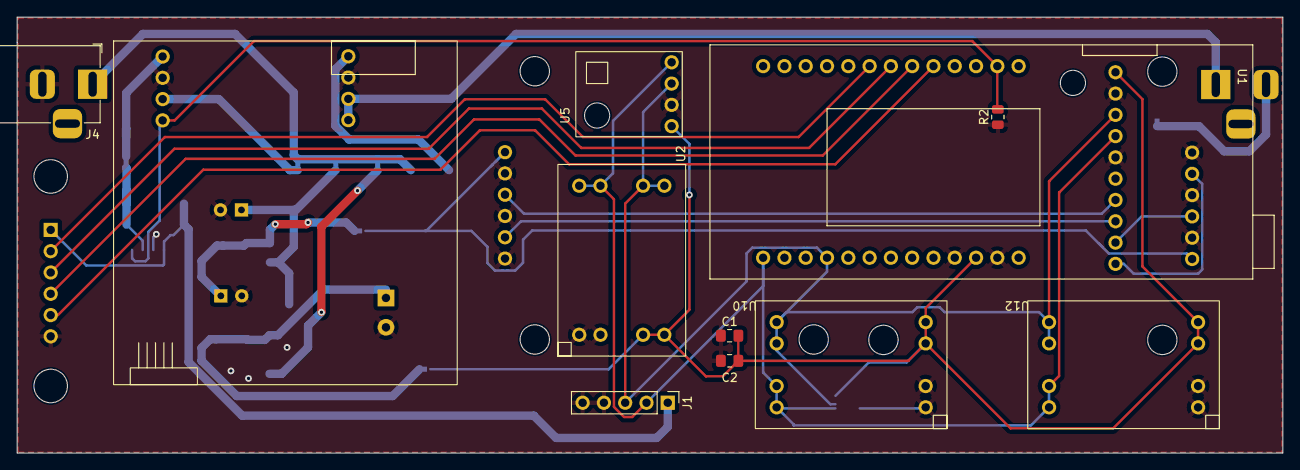
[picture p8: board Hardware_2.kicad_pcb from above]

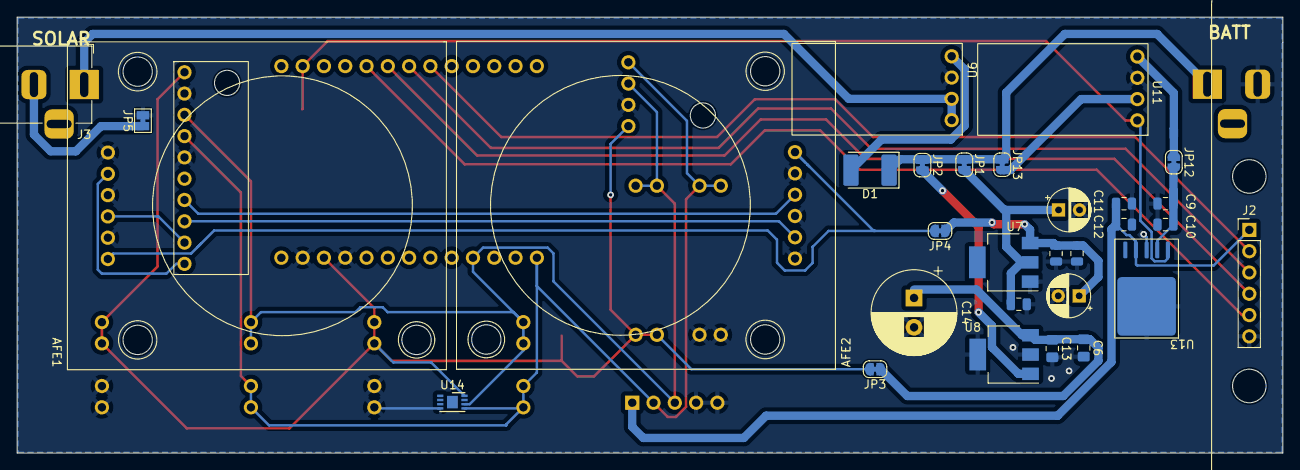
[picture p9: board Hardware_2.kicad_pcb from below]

Board: 2 copper layers, 151.0 x 52.0 mm, 43 parts (32 on the bottom side), 26 nets.

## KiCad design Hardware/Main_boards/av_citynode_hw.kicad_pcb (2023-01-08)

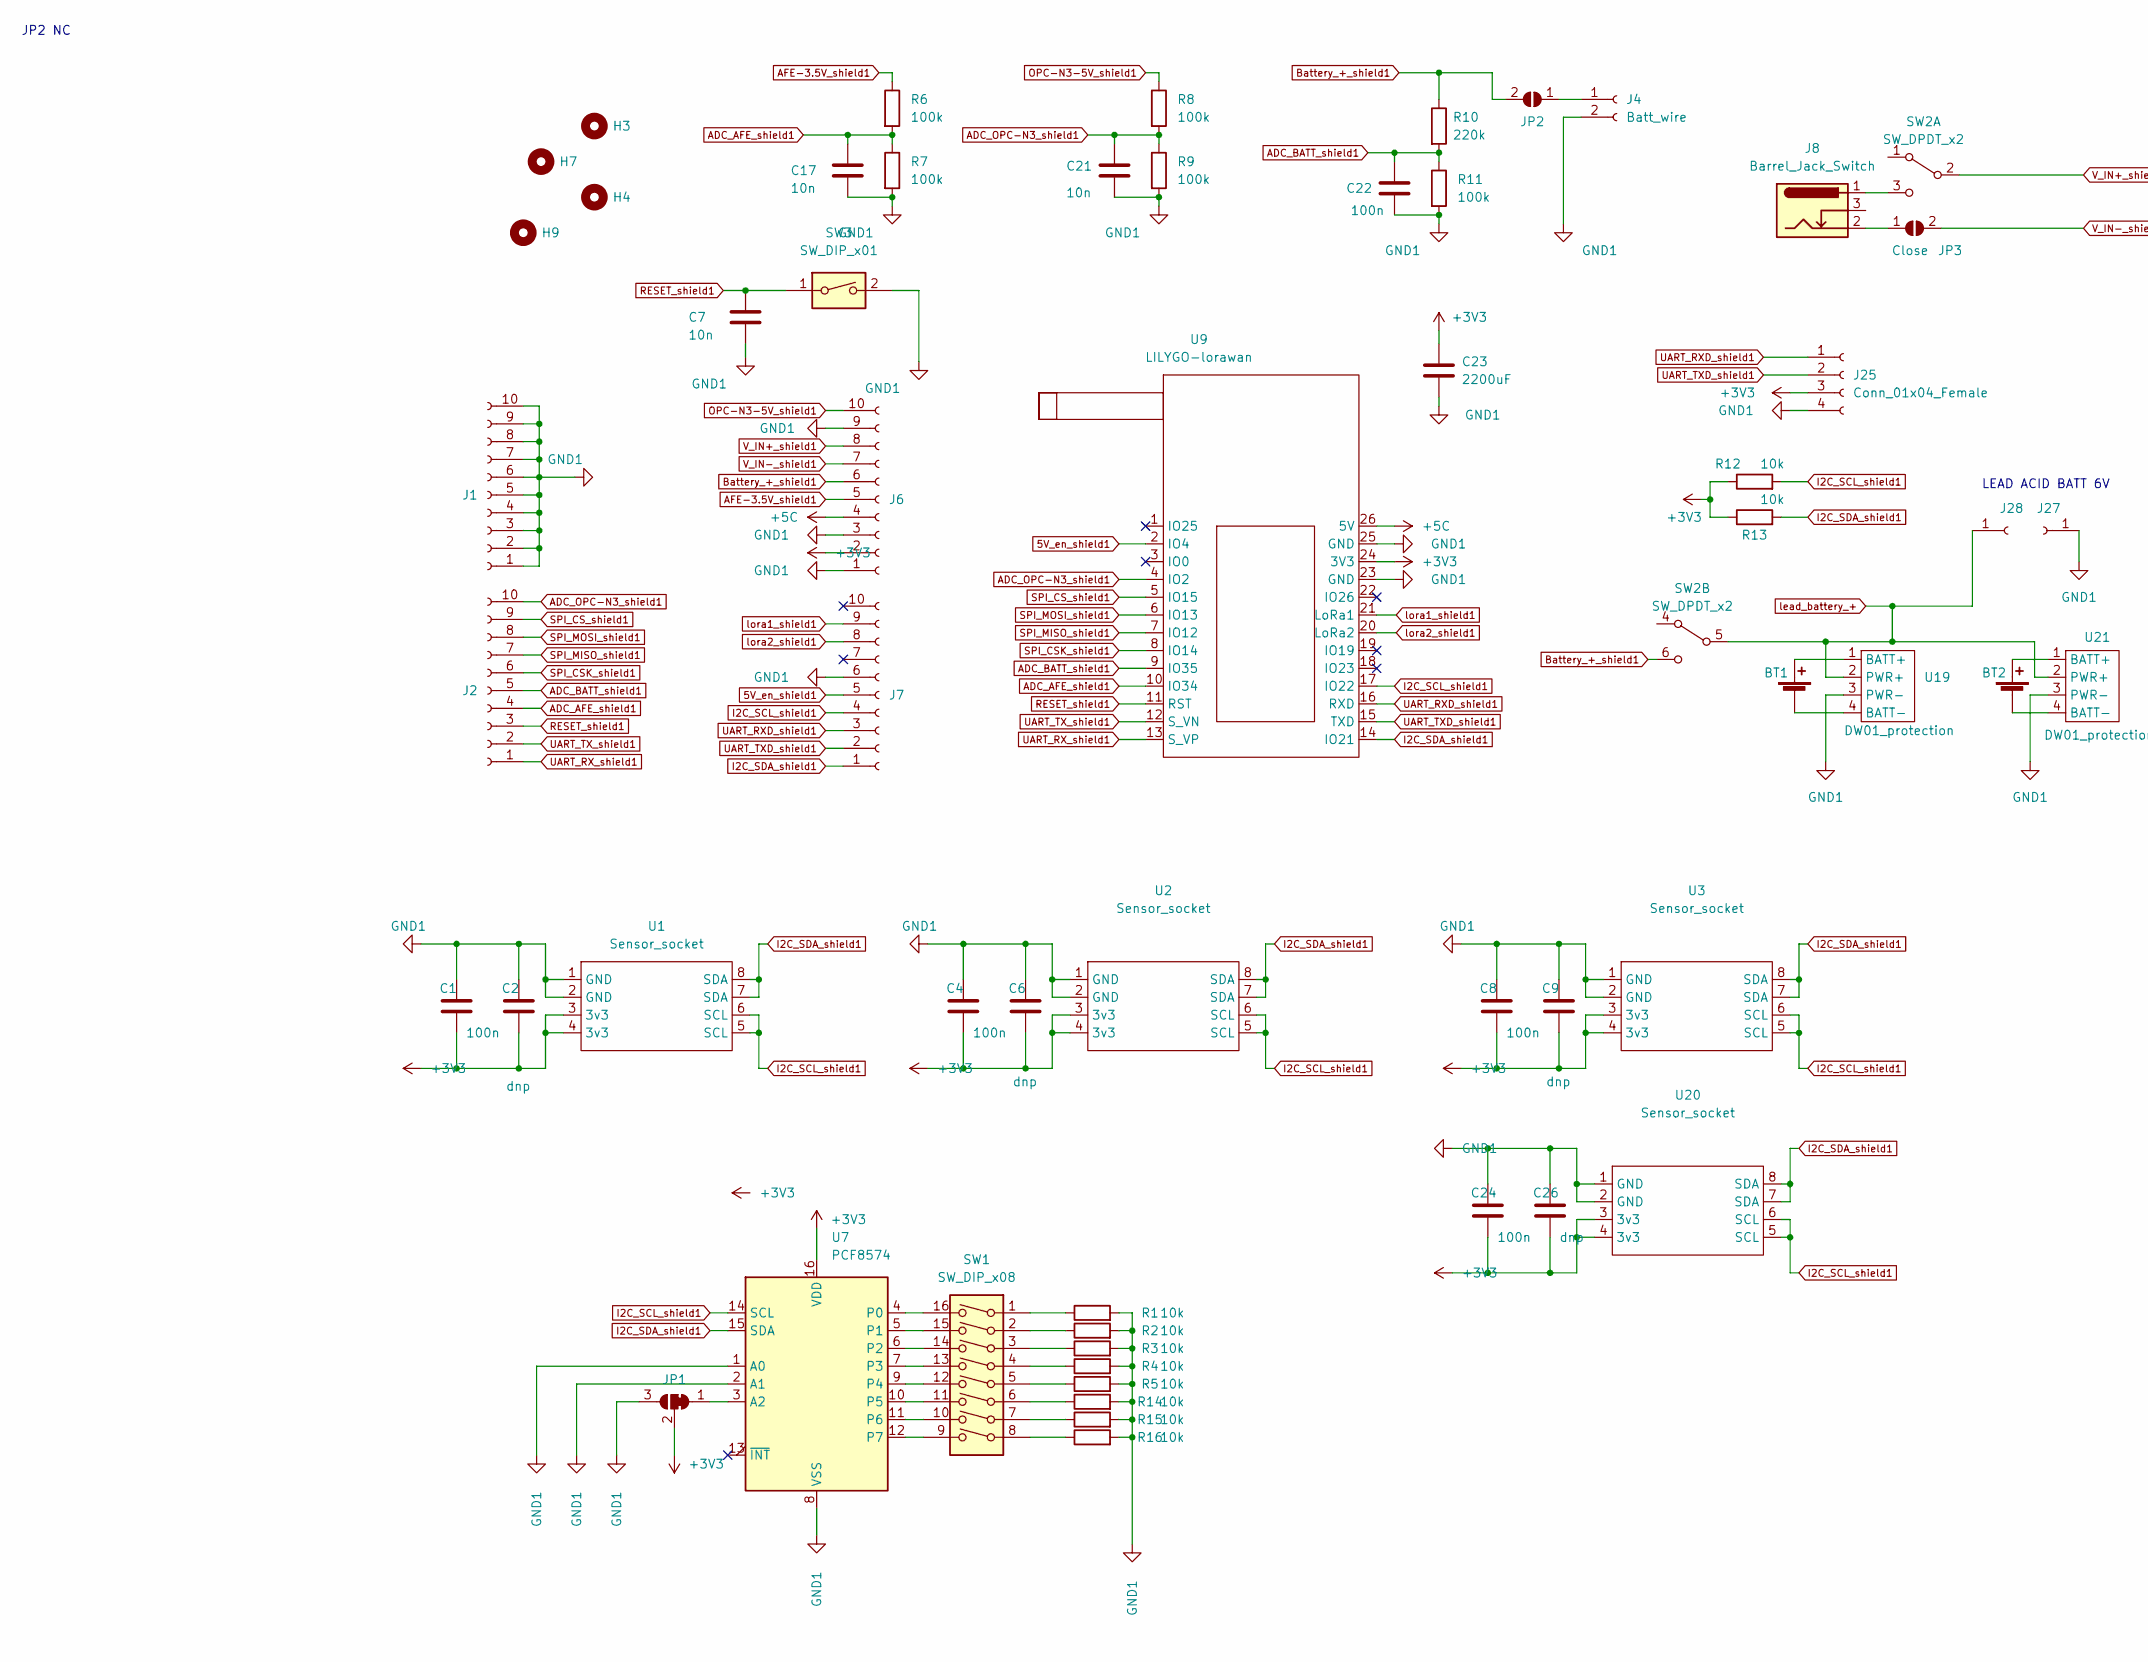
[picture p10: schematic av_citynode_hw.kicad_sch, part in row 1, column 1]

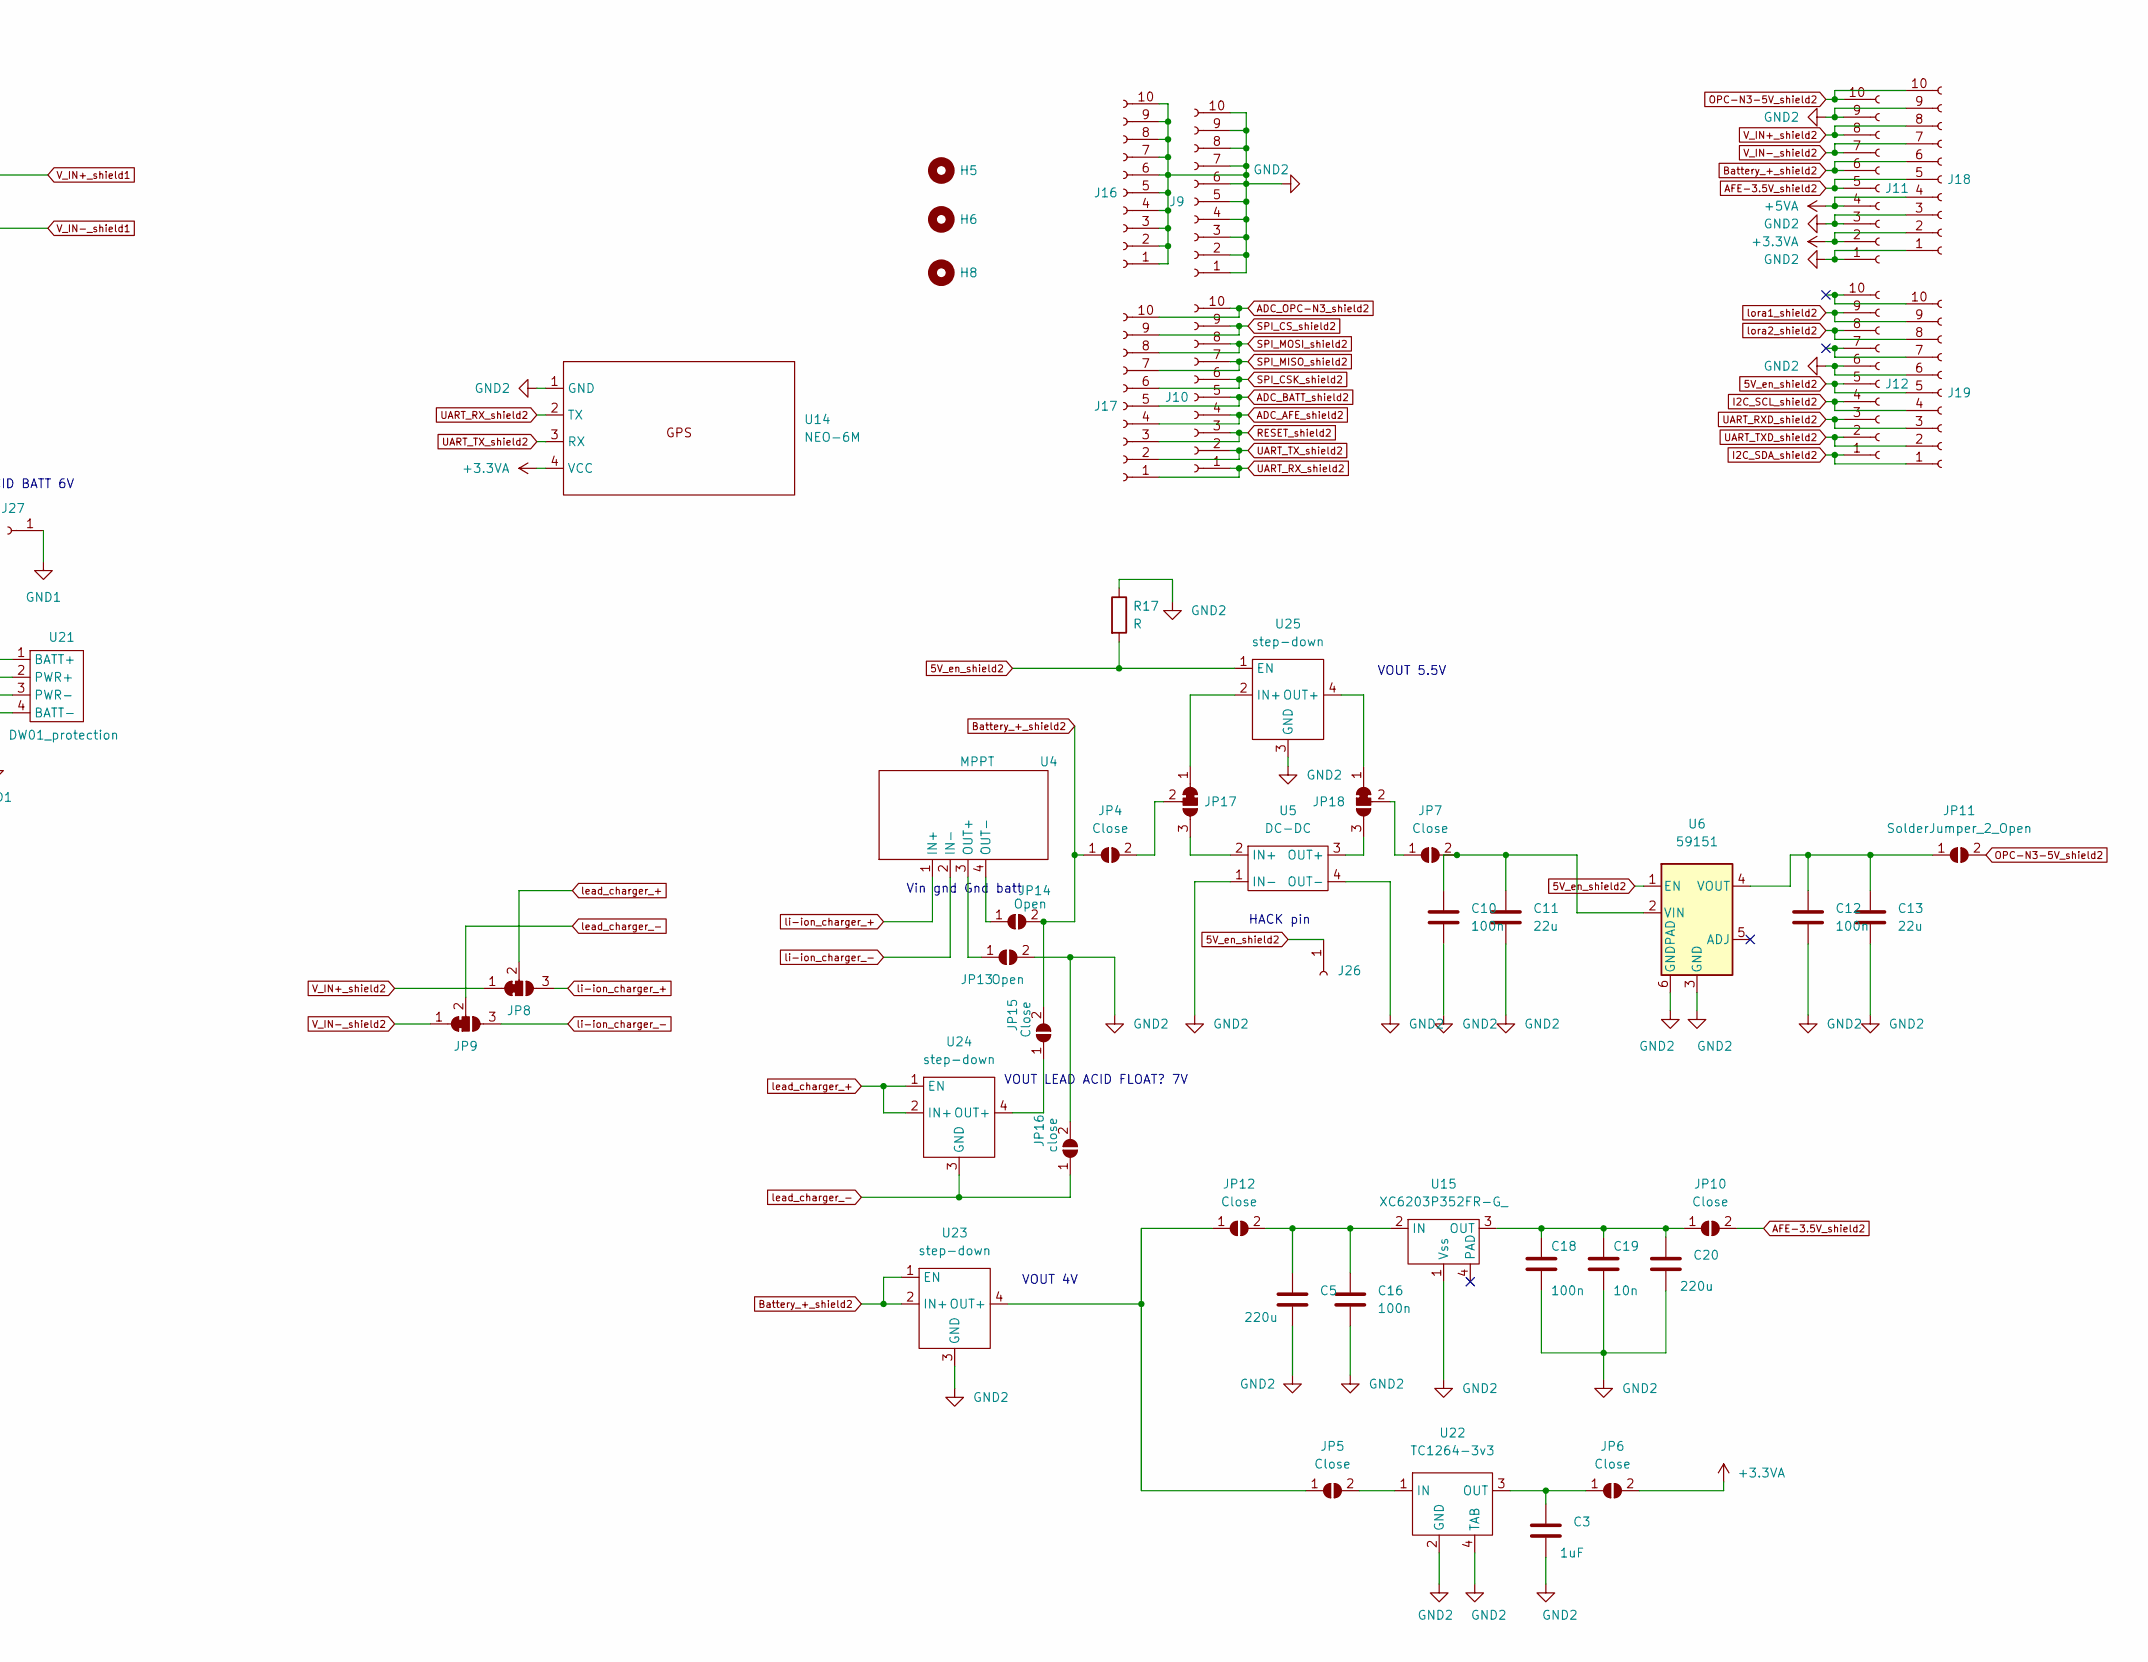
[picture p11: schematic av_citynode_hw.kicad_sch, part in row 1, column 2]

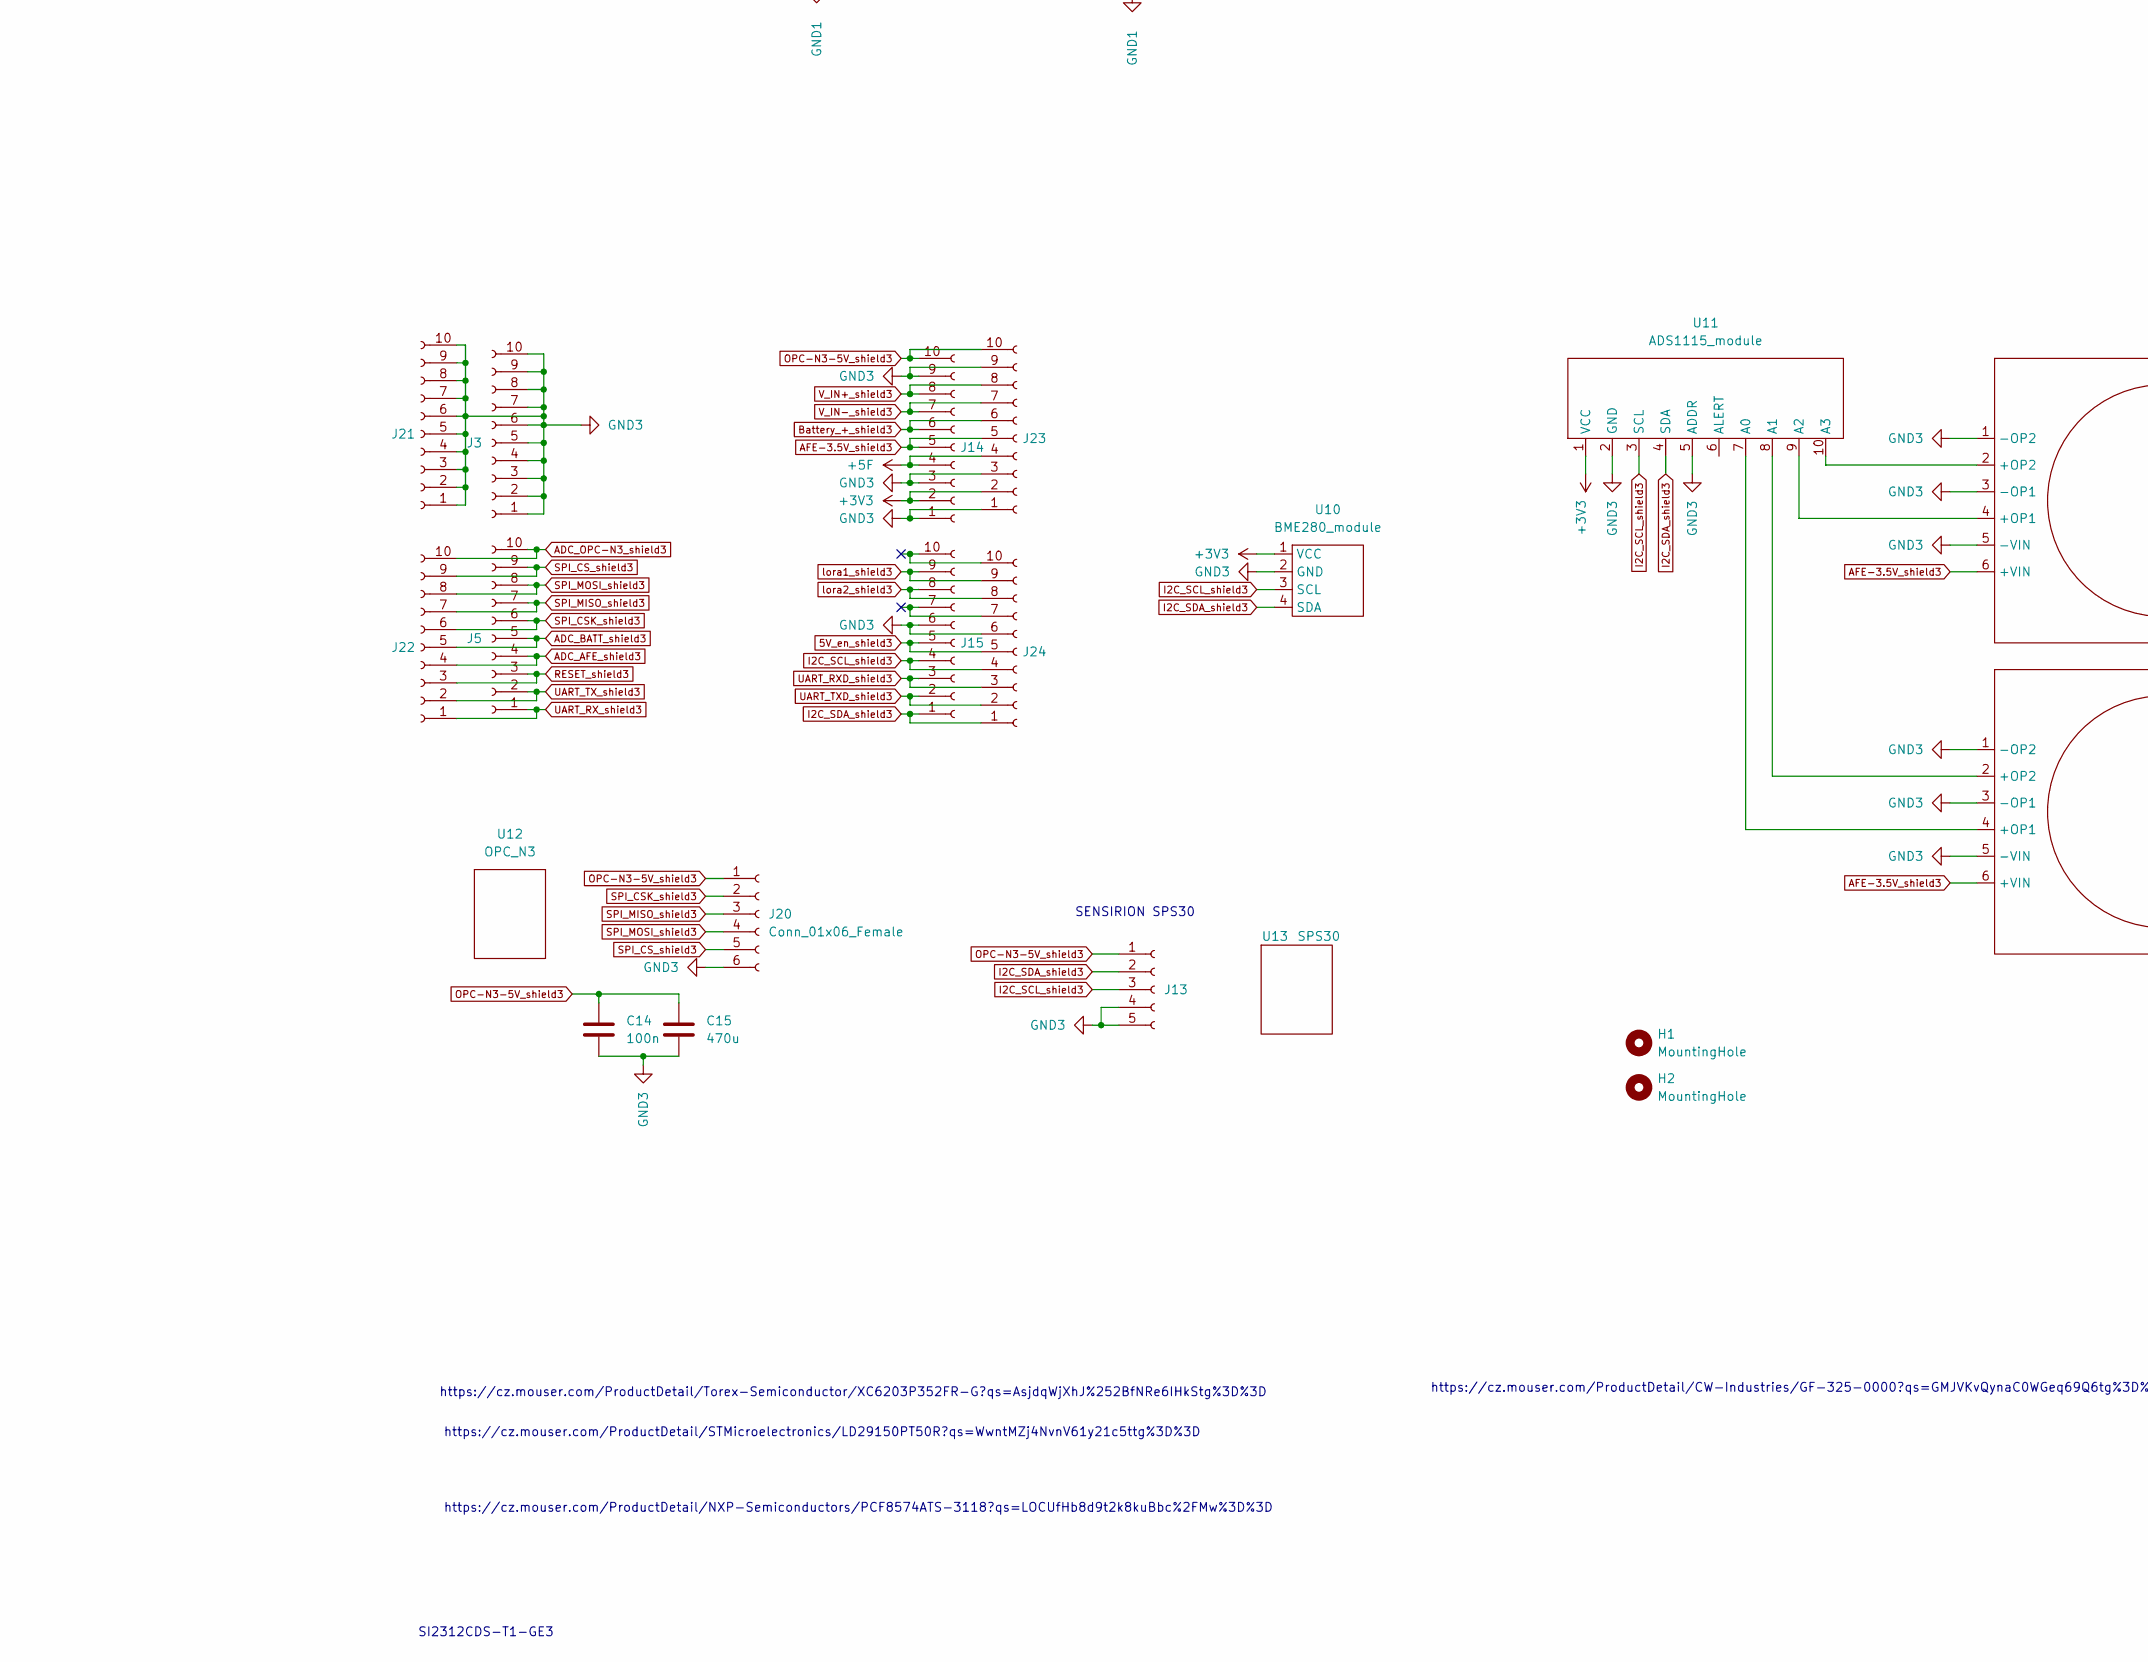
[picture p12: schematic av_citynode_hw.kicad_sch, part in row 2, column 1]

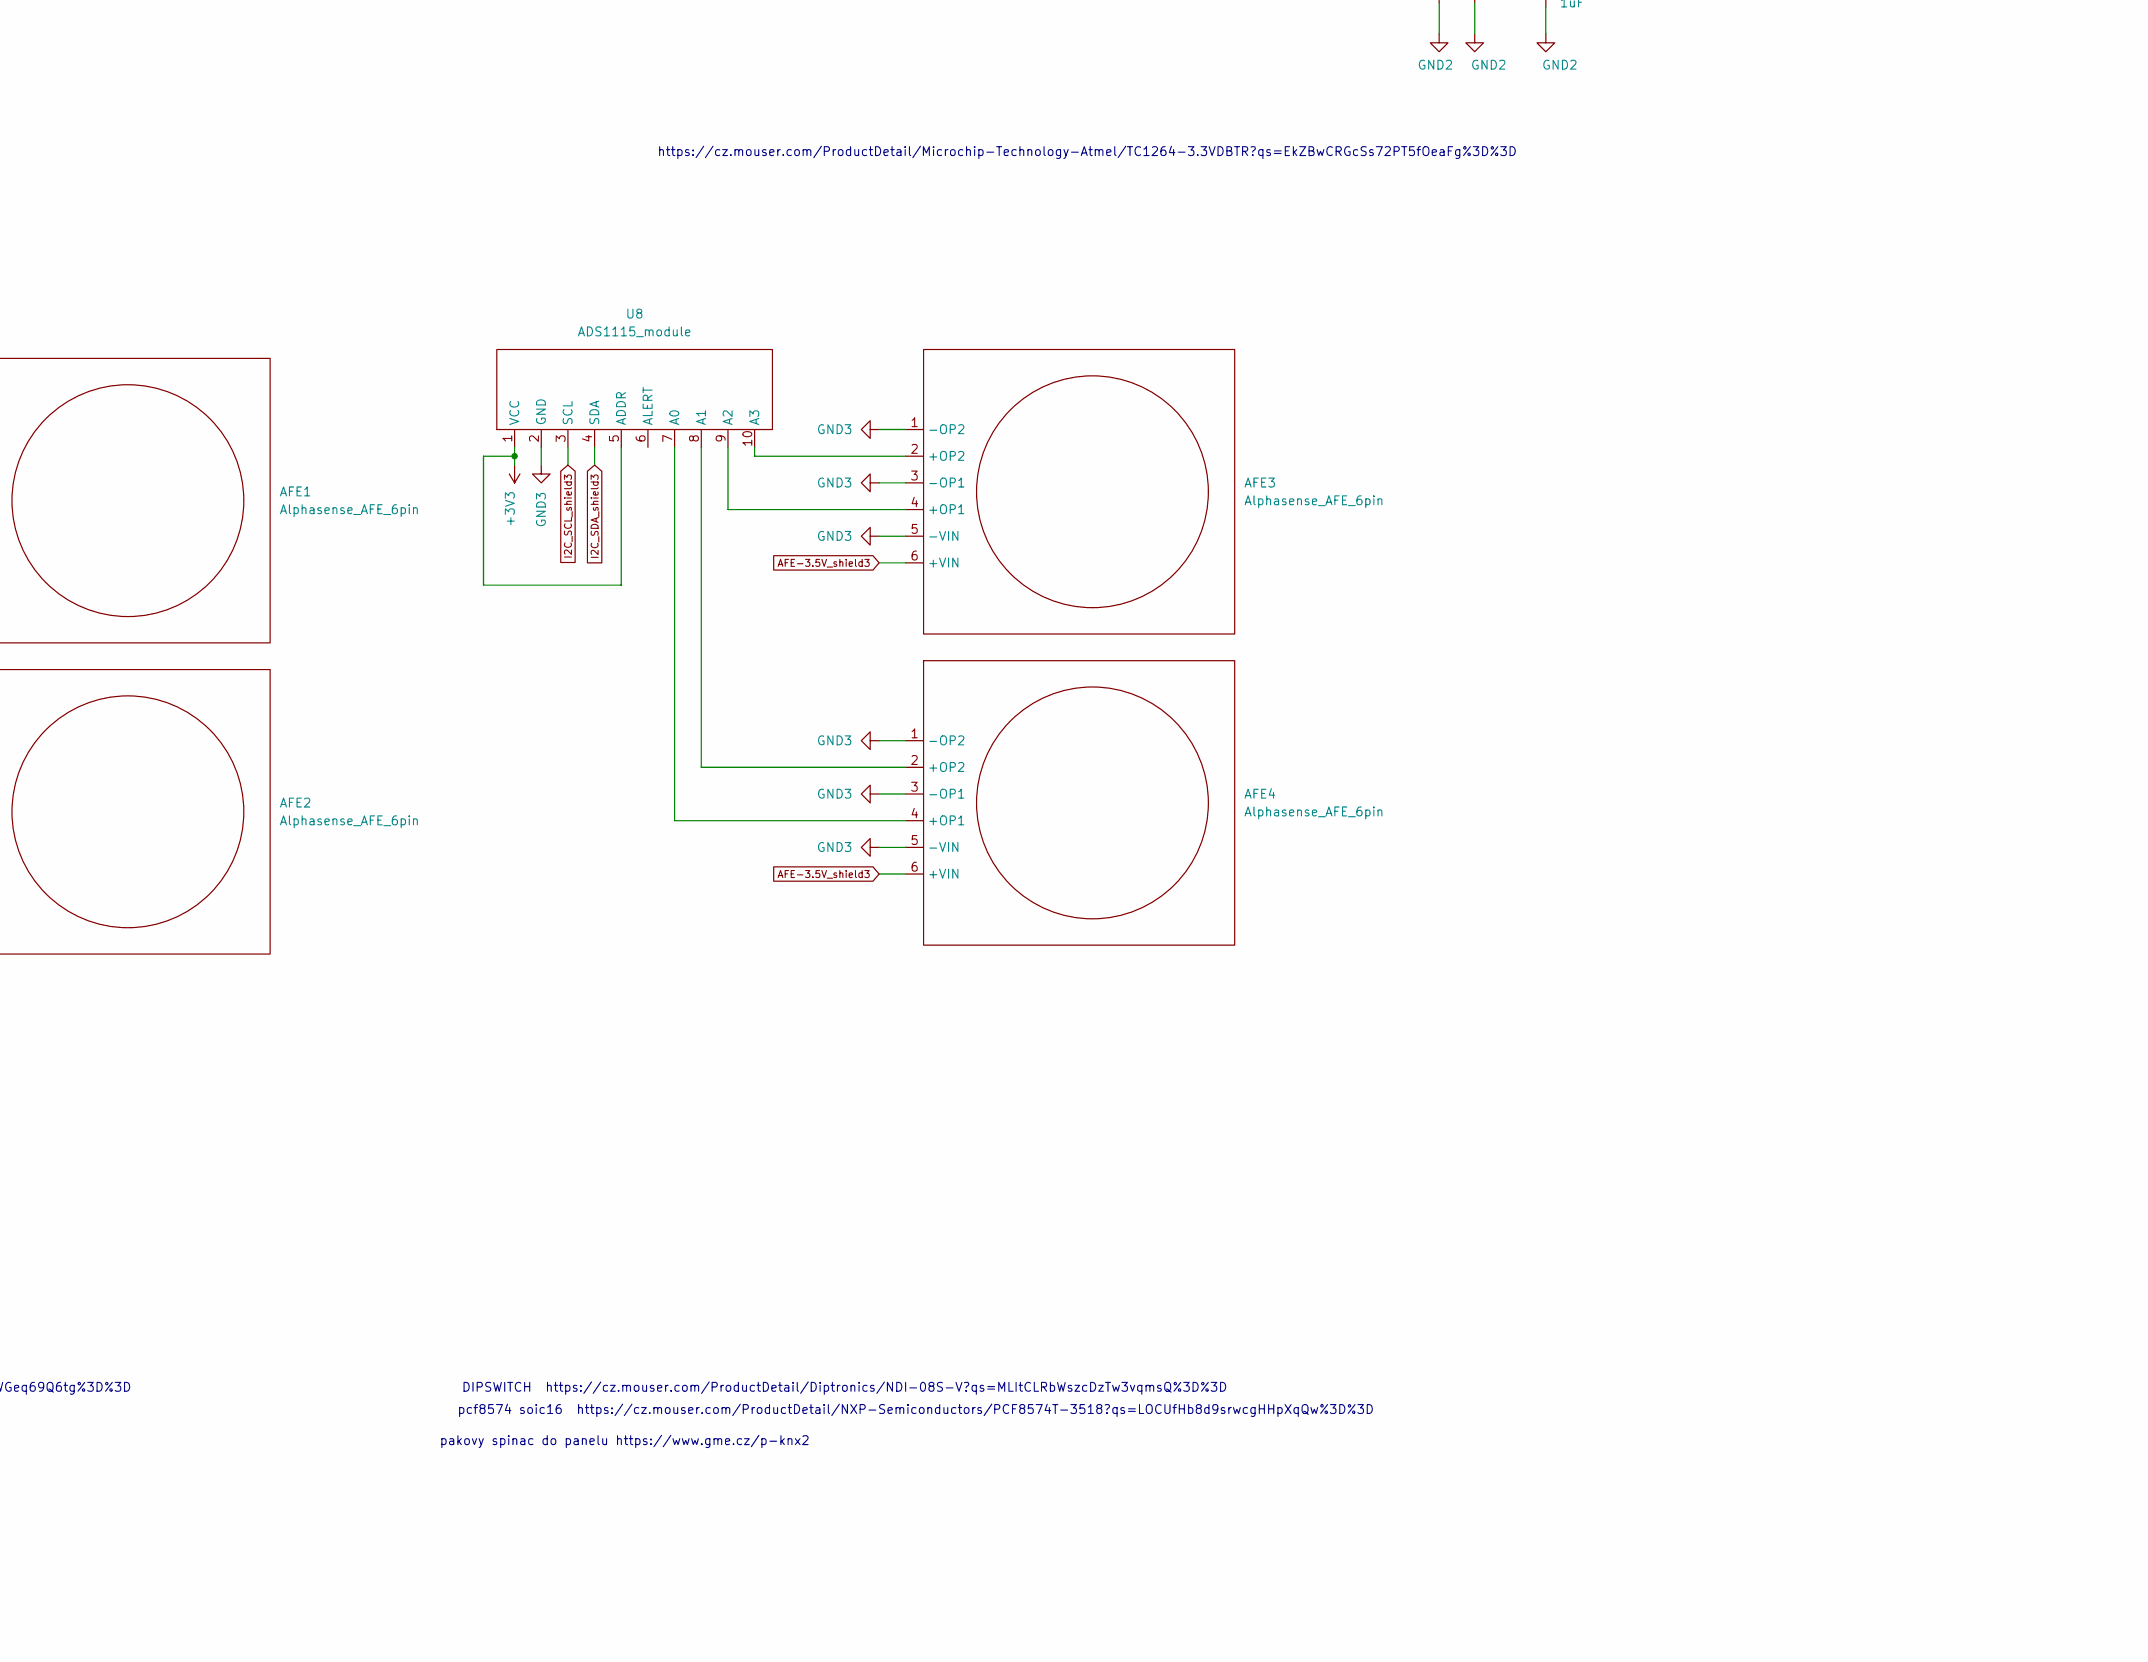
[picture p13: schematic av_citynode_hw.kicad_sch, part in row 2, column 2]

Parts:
AFE1, AFE3, AFE4: Alphasense_AFE_6pin; Alphasense_AFE_6pin-LEFT
AFE2: Alphasense_AFE_6pin; Alphasense_AFE_6pin-RIGHT
BT1, BT2: Battery_Cell; BatteryHolder_MPD_BH-18650-PC2
C1, C4, C8, C24: 100n; C_0805_2012Metric_Pad1.18x1.45mm_HandSolder
C2, C6, C9, C26: dnp; C_0805_2012Metric_Pad1.18x1.45mm_HandSolder
C3: 1uF; C_0805_2012Metric_Pad1.18x1.45mm_HandSolder
C5, C20: 220u; CP_Radial_D5.0mm_P2.50mm
C7, C17, C19, C21: 10n; C_0805_2012Metric
C10, C12, C14, C16, C18, C22: 100n; C_0805_2012Metric
C11, C13: 22u; C_0805_2012Metric
C15: 470u; CP_Radial_D10.0mm_P3.50mm
C23: 2200uF; CP_Radial_D12.5mm_P5.00mm
H1, H2, H3, H4, H5, H6, H9: MountingHole; MountingHole_4.3mm_M4
H7, H8: MountingHole; opc-n3-hole
J1, J2, J3, J5, J6, J7, J9, J10, J11, J12, J14, J15, J16, J17, J18, J19, J21, J22, J23, J24: Conn_01x10_Female; PinSocket_1x10_P2.54mm_Vertical
J4: Batt_wire; PinSocket_1x02_P2.54mm_Vertical
J8: Barrel_Jack_Switch; BarrelJack_Horizontal
J13: Conn_01x05_Female; PinHeader_1x05_P2.54mm_Vertical
J20: Conn_01x06_Female; PinHeader_1x06_P2.54mm_Vertical
J25: Conn_01x04_Female; PinSocket_1x04_P2.54mm_Vertical
J26: Conn_01x01_Female; PinHeader_1x01_P2.54mm_Vertical
J27, J28: Conn_01x01_Female; PinSocket_1x01_P2.54mm_Vertical
JP1: SolderJumper_3_Bridged12; SolderJumper-3_P1.3mm_Bridged12_RoundedPad1.0x1.5mm_NumberL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
JP2: SolderJumper_2_Open; SolderJumper-2_P1.3mm_Open_RoundedPad1.0x1.5mm
JP3: Close; SolderJumper-2_P1.3mm_Bridged_Pad1.0x1.5mm
JP4, JP5, JP6, JP7, JP10, JP12, JP15: Close; SolderJumper-2_P1.3mm_Bridged_RoundedPad1.0x1.5mm
JP8, JP9, JP17, JP18: SolderJumper_3_Bridged12; SolderJumper-3_P1.3mm_Bridged12_Pad1.0x1.5mm
JP11: SolderJumper_2_Open; SolderJumper-2_P1.3mm_Bridged_RoundedPad1.0x1.5mm
JP13, JP14: Open; SolderJumper-2_P1.3mm_Open_RoundedPad1.0x1.5mm
JP16: close; SolderJumper-2_P1.3mm_Bridged_RoundedPad1.0x1.5mm
R1, R2, R3, R4, R5, R12, R13, R14, R15, R16: 10k; R_0805_2012Metric
R6, R7, R8, R9, R11: 100k; R_0805_2012Metric
R10: 220k; R_0805_2012Metric
R17: R; R_0805_2012Metric
SW1: SW_DIP_x08; SW_DIP_SPSTx08_Slide_6.7x21.88mm_W7.62mm_P2.54mm_LowProfile
SW2: SW_DPDT_x2; Switch
SW3: SW_DIP_x01; SW_PUSH_6mm
U1, U2, U3, U20: Sensor_socket; Sensor_module
U4: MPPT; DC-DC
U5: DC-DC; STEP_UP
U6: 59151; PPAK
U7: PCF8574; SOIC-16_4.55x10.3mm_P1.27mm
U8, U11: ADS1115_module; ADS1115-module
U9: LILYGO-lorawan; LILYGO-LORAWAN
U10: BME280_module; BME280-module
U12: OPC_N3; opc-n3_3holes
U13: SPS30
U14: NEO-6M; NEO-6M-mod
U15: XC6203P352FR-G_; SOT-223
U19, U21: DW01_protection
U22: TC1264-3v3; SOT-223
U23, U24, U25: step-down; mp2315-module

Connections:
5V_en_shield1: J7.5, U9.2 (IO4)
5V_en_shield2: J12.5, J19.5, J26.1, R17.2, U6.1 (EN), U25.1 (EN)
5V_en_shield3: J15.5, J24.5
+3.3VA: J11.2, J18.2, JP6.2 (B), U14.4 (VCC)
+3V3: C1.2, C2.2, C4.2, C6.2, C8.2, C9.2, C23.1, C24.2, C26.2, J6.2, J14.2, J23.2, J25.3, JP1.2 (C), R12.1, R13.1, U1.3 (3v3), U1.4 (3v3), U2.3 (3v3), U2.4 (3v3), U3.3 (3v3), U3.4 (3v3), U7.16 (VDD), U8.1 (VCC), U8.5 (ADDR), U9.24 (3V3), U10.1 (VCC), U11.1 (VCC), U20.3 (3v3), U20.4 (3v3)
+5C: J6.4, U9.26 (5V)
+5F: J14.4, J23.4
+5VA: J11.4, J18.4
ADC_AFE_shield1: C17.1, J2.4, R6.2, R7.1, U9.10 (IO34)
ADC_AFE_shield2: J10.4, J17.4
ADC_AFE_shield3: J5.4, J22.4
ADC_BATT_shield1: C22.1, J2.5, R10.2, R11.1, U9.9 (IO35)
ADC_BATT_shield2: J10.5, J17.5
ADC_BATT_shield3: J5.5, J22.5
ADC_OPC-N3_shield1: C21.1, J2.10, R8.2, R9.1, U9.4 (IO2)
ADC_OPC-N3_shield2: J10.10, J17.10
ADC_OPC-N3_shield3: J5.10, J22.10
AFE-3.5V_shield1: J6.5, R6.1
AFE-3.5V_shield2: J11.5, J18.5, JP10.2 (B)
AFE-3.5V_shield3: AFE1.6 (+VIN), AFE2.6 (+VIN), AFE3.6 (+VIN), AFE4.6 (+VIN), J14.5, J23.5
Battery_+_shield1: J6.6, JP2.2 (B), R10.1, SW2.6 (C)
Battery_+_shield2: J11.6, J18.6, JP4.1 (A), JP14.2 (B), JP15.2 (B), U23.1 (EN), U23.2 (IN+)
Battery_+_shield3: J14.6, J23.6
GND1: C1.1, C2.1, C4.1, C6.1, C7.2, C8.1, C9.1, C17.2, C21.2, C22.2, C23.2, C24.1, C26.1, J1.1, J1.2, J1.3, J1.4, J1.5, J1.6, J1.7, J1.8, J1.9, J1.10, J4.2, J6.1, J6.3, J6.9, J7.6, J25.4, J27.1, JP1.3 (B), R1.2, R2.2, R3.2, R4.2, R5.2, R7.2, R9.2, R11.2, R14.2, R15.2, R16.2, SW3.2, U1.1 (GND), U1.2 (GND), U2.1 (GND), U2.2 (GND), U3.1 (GND), U3.2 (GND), U7.1 (A0), U7.2 (A1), U7.8 (VSS), U9.23 (GND), U9.25 (GND), U19.3 (PWR-), U20.1 (GND), U20.2 (GND), U21.3 (PWR-)
GND2: C3.2, C5.2, C10.2, C11.2, C12.2, C13.2, C16.2, C18.2, C19.2, C20.2, J9.1, J9.2, J9.3, J9.4, J9.5, J9.6, J9.7, J9.8, J9.9, J9.10, J11.1, J11.3, J11.9, J12.6, J16.1, J16.2, J16.3, J16.4, J16.5, J16.6, J16.7, J16.8, J16.9, J16.10, J18.1, J18.3, J18.9, J19.6, JP13.2 (B), JP16.2 (B), R17.1, U5.1 (IN-), U5.4 (OUT-), U6.3 (GND), U6.6 (GNDPAD), U14.1 (GND), U15.1 (Vss), U22.2 (GND), U22.4 (TAB), U23.3 (GND), U25.3 (GND)
GND3: AFE1.1 (-OP2), AFE1.3 (-OP1), AFE1.5 (-VIN), AFE2.1 (-OP2), AFE2.3 (-OP1), AFE2.5 (-VIN), AFE3.1 (-OP2), AFE3.3 (-OP1), AFE3.5 (-VIN), AFE4.1 (-OP2), AFE4.3 (-OP1), AFE4.5 (-VIN), C14.2, C15.2, J3.1, J3.2, J3.3, J3.4, J3.5, J3.6, J3.7, J3.8, J3.9, J3.10, J13.4, J13.5, J14.1, J14.3, J14.9, J15.6, J20.6, J21.1, J21.2, J21.3, J21.4, J21.5, J21.6, J21.7, J21.8, J21.9, J21.10, J23.1, J23.3, J23.9, J24.6, U8.2 (GND), U10.2 (GND), U11.2 (GND), U11.5 (ADDR)
I2C_SCL_shield1: J7.4, R12.2, U1.5 (SCL), U1.6 (SCL), U2.5 (SCL), U2.6 (SCL), U3.5 (SCL), U3.6 (SCL), U7.14 (SCL), U9.17 (IO22), U20.5 (SCL), U20.6 (SCL)
I2C_SCL_shield2: J12.4, J19.4
I2C_SCL_shield3: J13.3, J15.4, J24.4, U8.3 (SCL), U10.3 (SCL), U11.3 (SCL)
I2C_SDA_shield1: J7.1, R13.2, U1.7 (SDA), U1.8 (SDA), U2.7 (SDA), U2.8 (SDA), U3.7 (SDA), U3.8 (SDA), U7.15 (SDA), U9.14 (IO21), U20.7 (SDA), U20.8 (SDA)
I2C_SDA_shield2: J12.1, J19.1
I2C_SDA_shield3: J13.2, J15.1, J24.1, U8.4 (SDA), U10.4 (SDA), U11.4 (SDA)
unnamed: AFE1.2 (+OP2), U11.10 (A3)
unnamed: AFE1.4 (+OP1), U11.9 (A2)
unnamed: AFE2.2 (+OP2), U11.8 (A1)
unnamed: AFE2.4 (+OP1), U11.7 (A0)
unnamed: AFE3.2 (+OP2), U8.10 (A3)
unnamed: AFE3.4 (+OP1), U8.9 (A2)
unnamed: AFE4.2 (+OP2), U8.8 (A1)
unnamed: AFE4.4 (+OP1), U8.7 (A0)
unnamed: BT1.1 (+), U19.1 (BATT+)
unnamed: BT1.2 (-), U19.4 (BATT-)
unnamed: BT2.1 (+), U21.1 (BATT+)
unnamed: BT2.2 (-), U21.4 (BATT-)
unnamed: C3.1, JP6.1 (A), U22.3 (OUT)
unnamed: C10.1, C11.1, JP7.2 (B), U6.2 (VIN)
unnamed: C12.1, C13.1, JP11.1 (A), U6.4 (VOUT)
unnamed: C5.1, C16.1, JP12.2 (B), U15.2 (IN)
unnamed: C18.1, C19.1, C20.1, JP10.1 (A), U15.3 (OUT)
unnamed: J4.1, JP2.1 (A)
unnamed: J8.1, SW2.3 (C)
unnamed: J8.2, JP3.1 (A)
unnamed: JP1.1 (A), U7.3 (A2)
unnamed: JP5.2 (B), U22.1 (IN)
unnamed: JP5.1 (A), JP12.1 (A), U23.4 (OUT+)
unnamed: JP13.1 (A), U4.3 (OUT+)
unnamed: JP14.1 (A), U4.4 (OUT-)
unnamed: JP15.1 (A), U24.4 (OUT+)
unnamed: JP17.1 (A), U25.2 (IN+)
unnamed: JP4.2 (B), JP17.2 (C)
unnamed: JP17.3 (B), U5.2 (IN+)
unnamed: JP18.1 (A), U25.4 (OUT+)
unnamed: JP7.1 (A), JP18.2 (C)
unnamed: JP18.3 (B), U5.3 (OUT+)
unnamed: R1.1, SW1.1
unnamed: R2.1, SW1.2
unnamed: R3.1, SW1.3
unnamed: R4.1, SW1.4
unnamed: R5.1, SW1.5
unnamed: R14.1, SW1.6
unnamed: R15.1, SW1.7
unnamed: R16.1, SW1.8
unnamed: SW1.9, U7.12 (P7)
unnamed: SW1.10, U7.11 (P6)
unnamed: SW1.11, U7.10 (P5)
unnamed: SW1.12, U7.9 (P4)
unnamed: SW1.13, U7.7 (P3)
unnamed: SW1.14, U7.6 (P2)
unnamed: SW1.15, U7.5 (P1)
unnamed: SW1.16, U7.4 (P0)
OPC-N3-5V_shield1: J6.10, R8.1
OPC-N3-5V_shield2: J11.10, J18.10, JP11.2 (B)
OPC-N3-5V_shield3: C14.1, C15.1, J13.1, J14.10, J20.1, J23.10
RESET_shield1: C7.1, J2.3, SW3.1, U9.11 (RST)
RESET_shield2: J10.3, J17.3
RESET_shield3: J5.3, J22.3
SPI_CSK_shield1: J2.6, U9.8 (IO14)
SPI_CSK_shield2: J10.6, J17.6
SPI_CSK_shield3: J5.6, J20.2, J22.6
SPI_CS_shield1: J2.9, U9.5 (IO15)
SPI_CS_shield2: J10.9, J17.9
SPI_CS_shield3: J5.9, J20.5, J22.9
SPI_MISO_shield1: J2.7, U9.7 (IO12)
SPI_MISO_shield2: J10.7, J17.7
SPI_MISO_shield3: J5.7, J20.3, J22.7
SPI_MOSI_shield1: J2.8, U9.6 (IO13)
SPI_MOSI_shield2: J10.8, J17.8
SPI_MOSI_shield3: J5.8, J20.4, J22.8
UART_RXD_shield1: J7.3, J25.1, U9.16 (RXD)
UART_RXD_shield2: J12.3, J19.3
UART_RXD_shield3: J15.3, J24.3
UART_RX_shield1: J2.1, U9.13 (S_VP)
UART_RX_shield2: J10.1, J17.1, U14.2 (TX)
UART_RX_shield3: J5.1, J22.1
UART_TXD_shield1: J7.2, J25.2, U9.15 (TXD)
UART_TXD_shield2: J12.2, J19.2
UART_TXD_shield3: J15.2, J24.2
UART_TX_shield1: J2.2, U9.12 (S_VN)
UART_TX_shield2: J10.2, J17.2, U14.3 (RX)
UART_TX_shield3: J5.2, J22.2
V_IN+_shield1: J6.8, SW2.2 (B)
V_IN+_shield2: J11.8, J18.8, JP8.1 (A)
V_IN+_shield3: J14.8, J23.8
V_IN-_shield1: J6.7, JP3.2 (B)
V_IN-_shield2: J11.7, J18.7, JP9.1 (A)
V_IN-_shield3: J14.7, J23.7
lead_battery_+: J28.1, SW2.5 (B), U19.2 (PWR+), U21.2 (PWR+)
lead_charger_+: JP8.2 (C), U24.1 (EN), U24.2 (IN+)
lead_charger_-: JP9.2 (C), JP16.1 (A), U24.3 (GND)
li-ion_charger_+: JP8.3 (B), U4.1 (IN+)
li-ion_charger_-: JP9.3 (B), U4.2 (IN-)
lora1_shield1: J7.9, U9.21 (LoRa1)
lora1_shield2: J12.9, J19.9
lora1_shield3: J15.9, J24.9
lora2_shield1: J7.8, U9.20 (LoRa2)
lora2_shield2: J12.8, J19.8
lora2_shield3: J15.8, J24.8

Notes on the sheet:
pakovy spinac do panelu https://www.gme.cz/p-knx2
https://cz.mouser.com/ProductDetail/NXP-Semiconductors/PCF8574ATS-3118?qs=LOCUfHb8d9t2k8kuBbc%2FMw%3D%3D
Vin gnd Gnd batt
DIPSWITCH https://cz.mouser.com/ProductDetail/Diptronics/NDI-08S-V?qs=MLItCLRbWszcDzTw3vqmsQ%3D%3D
VOUT 4V
JP2 NC
SI2312CDS-T1-GE3
pcf8574 soic16 https://cz.mouser.com/ProductDetail/NXP-Semiconductors/PCF8574T-3518?qs=LOCUfHb8d9srwcgHHpXqQw%3D%3D
https://cz.mouser.com/ProductDetail/CW-Industries/GF-325-0000?qs=GMJVKvQynaC0WGeq69Q6tg%3D%3D
https://cz.mouser.com/ProductDetail/STMicroelectronics/LD29150PT50R?qs=WwntMZj4NvnV61y21c5ttg%3D%3D
VOUT LEAD ACID FLOAT? 7V
SENSIRION SPS30
https://cz.mouser.com/ProductDetail/Microchip-Technology-Atmel/TC1264-3.3VDBTR?qs=EkZBwCRGcSs72PT5fOeaFg%3D%3D
https://cz.mouser.com/ProductDetail/Torex-Semiconductor/XC6203P352FR-G?qs=AsjdqWjXhJ%252BfNRe6IHkStg%3D%3D
VOUT 5.5V
HACK pin
LEAD ACID BATT 6V

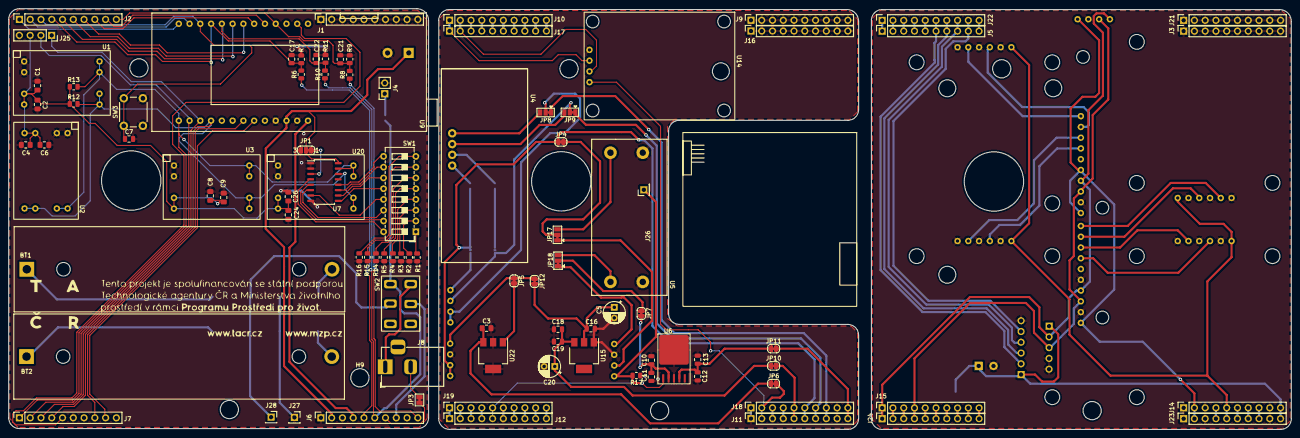
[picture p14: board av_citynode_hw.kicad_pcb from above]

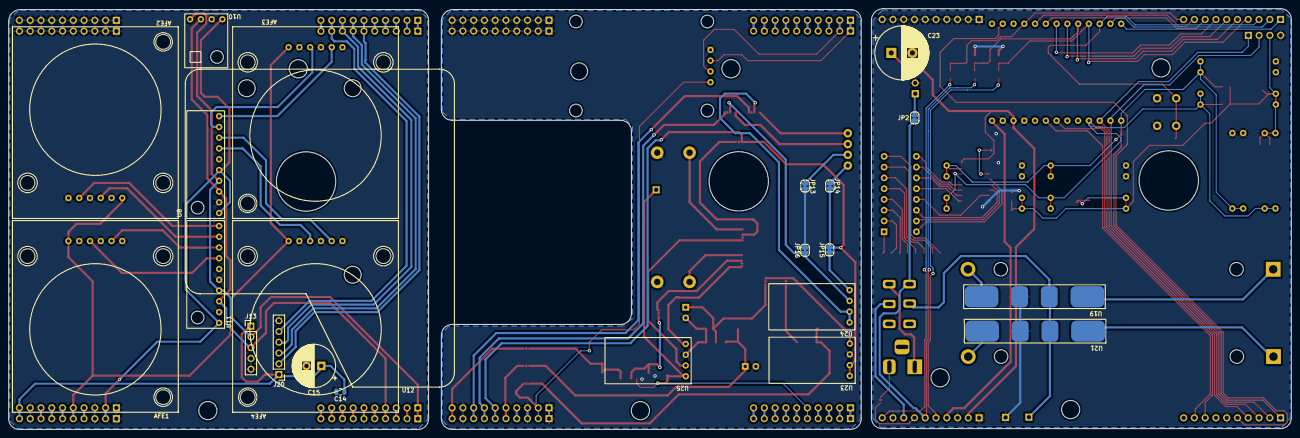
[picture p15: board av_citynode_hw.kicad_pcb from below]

Board: 2 copper layers, 302.6 x 99.3 mm, 128 parts (23 on the bottom side), 127 nets.

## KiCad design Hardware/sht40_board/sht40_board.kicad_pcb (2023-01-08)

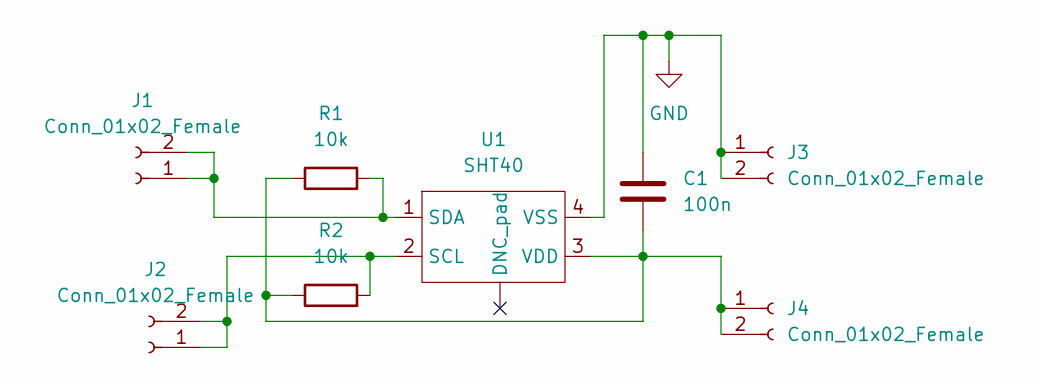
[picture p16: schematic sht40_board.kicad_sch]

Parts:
C1: 100n; C_0805_2012Metric
J1, J2, J3, J4: Conn_01x02_Female; PinHeader_1x02_P2.54mm_Vertical
R1, R2: 10k; R_0805_2012Metric
U1: SHT40

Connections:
GND: C1.1, J3.1, J3.2, U1.4 (VSS)
unnamed: C1.2, J4.1, J4.2, R1.1, R2.1, U1.3 (VDD)
unnamed: J1.1, J1.2, R1.2, U1.1 (SDA)
unnamed: J2.1, J2.2, R2.2, U1.2 (SCL)



Board: 2 copper layers, 20.3 x 15.2 mm, 8 parts (6 on the bottom side), 4 nets.

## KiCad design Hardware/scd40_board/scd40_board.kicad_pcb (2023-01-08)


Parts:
J1, J2, J3, J4: Conn_01x02_Female; PinHeader_1x02_P2.54mm_Vertical
R1, R2: R; R_0805_2012Metric
U1: scd40; SCD40

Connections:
GND: J2.1, J2.2, U1.6 (GND), U1.20 (GND), U1.21 (GNDpad), U1.22 (gndpad), U1.23 (gndpad), U1.24 (gndpad)
unnamed: J1.1, J1.2, R1.1, R2.1, U1.7 (VDD), U1.19 (VDDH)
unnamed: J3.1, J3.2, R1.2, U1.10 (SDA)
unnamed: J4.1, J4.2, R2.2, U1.9 (SCL)



Board: 2 copper layers, 22.9 x 15.2 mm, 7 parts (6 on the bottom side), 4 nets.

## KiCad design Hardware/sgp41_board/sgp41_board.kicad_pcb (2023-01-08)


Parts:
C1, C2: 1u; C_0805_2012Metric
J1, J2, J3, J4: Conn_01x02_Female; PinHeader_1x02_P2.54mm_Vertical
R1, R3: Rp; R_0805_2012Metric
R2: 4R7; R_0805_2012Metric
U1: sgp41

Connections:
GND: C1.1, C2.2, J2.1, J2.2, U1.2 (VSS), U1.4 (n/a), U1.7 (diepad)
unnamed: C1.2, R2.1, U1.1 (VDD)
unnamed: C2.1, J1.1, J1.2, R1.1, R2.2, R3.1, U1.5 (VDDH)
unnamed: J4.1, J4.2, R1.2, U1.3 (SDA)
unnamed: J3.1, J3.2, R3.2, U1.6 (SCL)



Board: 2 copper layers, 22.9 x 15.2 mm, 10 parts (6 on the bottom side), 5 nets.

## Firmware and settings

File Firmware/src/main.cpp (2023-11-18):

#include "main.h"
#include "hardware/hardware.h"
#include "hardware/wifi-support.h"
#include "Arduino.h"


//        ██████  ▒█████   ▄▄▄        ██████ ▓█████  ███▄    █   ██████ ▓█████             
//      ▒██    ▒ ▒██▒  ██▒▒████▄    ▒██    ▒ ▓█   ▀  ██ ▀█   █ ▒██    ▒ ▓█   ▀             
//      ░ ▓██▄   ▒██░  ██▒▒██  ▀█▄  ░ ▓██▄   ▒███   ▓██  ▀█ ██▒░ ▓██▄   ▒███               
//        ▒   ██▒▒██   ██░░██▄▄▄▄██   ▒   ██▒▒▓█  ▄ ▓██▒  ▐▌██▒  ▒   ██▒▒▓█  ▄             
//      ▒██████▒▒░ ████▓▒░ ▓█   ▓██▒▒██████▒▒░▒████▒▒██░   ▓██░▒██████▒▒░▒████▒            
//      ▒ ▒▓▒ ▒ ░░ ▒░▒░▒░  ▒▒   ▓▒█░▒ ▒▓▒ ▒ ░░░ ▒░ ░░ ▒░   ▒ ▒ ▒ ▒▓▒ ▒ ░░░ ▒░ ░            
//      ░ ░▒  ░ ░  ░ ▒ ▒░   ▒   ▒▒ ░░ ░▒  ░ ░ ░ ░  ░░ ░░   ░ ▒░░ ░▒  ░ ░ ░ ░  ░            
//      ░  ░  ░  ░ ░ ░ ▒    ░   ▒   ░  ░  ░     ░      ░   ░ ░ ░  ░  ░     ░               
//            ░      ░ ░        ░  ░      ░     ░  ░         ░       ░     ░  ░            
//                                                                                         
//                      ███▄    █  ▒█████  ▓█████▄ ▓█████                                  
//                      ██ ▀█   █ ▒██▒  ██▒▒██▀ ██▌▓█   ▀                                  
//                     ▓██  ▀█ ██▒▒██░  ██▒░██   █▌▒███                                    
//                     ▓██▒  ▐▌██▒▒██   ██░░▓█▄   ▌▒▓█  ▄                                  
//                     ▒██░   ▓██░░ ████▓▒░░▒████▓ ░▒████▒                                 
//                     ░ ▒░   ▒ ▒ ░ ▒░▒░▒░  ▒▒▓  ▒ ░░ ▒░ ░                                 
//                     ░ ░░   ░ ▒░  ░ ▒ ▒░  ░ ▒  ▒  ░ ░  ░                                 
//                        ░   ░ ░ ░ ░ ░ ▒   ░ ░  ░    ░                                    
//                              ░     ░ ░     ░       ░  ░                                 
//                                          ░                                                 


node_object_t node_object;

#ifdef DO_DEEP_SLEEP
#define uS_TO_S_FACTOR 1000000  /* Conversion factor for micro seconds to seconds */
#define TIME_TO_SLEEP  60*3        /* Time ESP32 will go to sleep (in seconds) */
#endif


#include "soc/soc.h"
#include "soc/rtc_cntl_reg.h"


void setup() 
{
    // FIXME stupid lilygo board 
    WRITE_PERI_REG(RTC_CNTL_BROWN_OUT_REG, 0); //disable brownout detector

    esp_task_wdt_init(WDT_TIMEOUT, true);  // enable panic so ESP32 restarts
    esp_task_wdt_add(NULL);

    initOutputs();

    hardwareHandleEEPROM(&node_object);

    hardwareGetMAC(&node_object);

    hardwareSetup(&node_object);

    if((strcmp("LIGHT_01", node_object.provision.device_name) != 0) || \
       (strcmp("LIGHT_02", node_object.provision.device_name) != 0)){
      if(CONNECTIVITY_ERASE_CREDENTIALS) {
          delete_wifi_credentials();
          uiEraseCredentialsAndWait();
#ifdef USE_DISPLAY
          uiDisplayProvision();
#endif
          uiSerialProvision();
          while(1)
            ;
      } else if(DISPLAY_ON){
          uiDisplayHeader(&node_object);
      }
    }

    if(SERIAL_OUTPUT_ON && SERIAL_OUTPUT_DBG){
        uiPrintHeader();
    }

    if(MODE_USE_LORAWAN)
    {
        // TODO Lorawan stuff
        //initLmic();
    } else if(MODE_USE_WIFI)
    {
        node_object.setup.behaviour.seconds_to_loop = WIFI_SECONDS_TO_LOOP_DEFAULT;
        node_object.setup.behaviour.minutes_to_fwupdate_check = WIFI_MINUTES_TO_FWUPDATE_CHECK_DEFAULT;
        node_object.setup.behaviour.minutes_to_reconfigure = WIFI_MINUTES_TO_RECONFIGURE;
        node_object.setup.behaviour.minutes_to_sensors_metadata = WIFI_MINUTES_TO_SENSORS_METADATA_DEFAULT;
        wifimode_setup();
    }

    uiDisplayHwInit();

  if(strcmp("LIGHT_02", node_object.provision.device_name) != 0){
    hardwareInit(&node_object);
  }
#ifdef DO_DEEP_SLEEP
  esp_sleep_enable_timer_wakeup(TIME_TO_SLEEP * uS_TO_S_FACTOR);
#endif
}

void loop() 
{
    if(MODE_USE_LORAWAN)
    {
        // LMIC: os_runloop_once();
    } else if(MODE_USE_WIFI)
    {
        wifimode_loop(&node_object);
    }
}

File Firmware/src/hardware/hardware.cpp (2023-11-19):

#include "stdio.h"
#include <Adafruit_BME280.h>
#include "internal_adc.h"
#include "hardware.h"
#include "opcn3.h"
#include "bme280.h"
#include "ads1115.h"
#include "fis3031.h"
#include "gps.h"
#include "sensirion-sps30.h"
#include "sps30.h"
#include "pcf8574_expander.h"
#include "eeprom.h"
#include "ui/ui.h"

#include "wifi-support.h"


void hardwareHandleEEPROM(node_object_t *handle){
    #if (EEPROM_MODE == EEPROM_PROVISION)
      eraseProvisionedData();
      provisionDevice();
      //serial.println("EEPROM provisioned: ");
      readProvisionedData(handle);
      uiPrintProvision(handle);
      while(1)
        ;
    #elif (EEPROM_MODE == EEPROM_ERASE)
      eraseProvisionedData();
      //serial.println("EEPROM erased: ");
      while(1)
        ;
    #elif (EEPROM_MODE == EEPROM_SHOW)
      readProvisionedData(handle);
      uiPrintProvision(handle);
    #endif
}

void hardwareEnable5V(){
    gpio_pulldown_en(ENABLE_5V_PIN);
    gpio_set_direction(ENABLE_5V_PIN, GPIO_MODE_OUTPUT);
    gpio_set_level(ENABLE_5V_PIN, 1);
    delay(50);
}

void hardwareDisable5V(){
    gpio_pulldown_en(ENABLE_5V_PIN);
    gpio_set_direction(ENABLE_5V_PIN, GPIO_MODE_OUTPUT);
    gpio_set_level(ENABLE_5V_PIN, 0);
    delay(50);
}

void hardwareGetMAC(node_object_t *node_object){
    esp_efuse_mac_get_default(node_object->mac_addr);
}

void hardwareSetup(node_object_t *node_object){
  uint8_t microswitches = get_setup_switches();
  if (microswitches & SW_POS_8) {
    node_object->setup.sw_pos_8 = true;
  } else {
    node_object->setup.sw_pos_8 = false;
  }
  if (microswitches & SW_POS_7) {
    node_object->setup.sw_pos_7 = true;
  } else {
    node_object->setup.sw_pos_7 = false;
  }
  if (microswitches & SW_POS_6) {
    node_object->setup.sw_pos_6 = true;
  } else {
    node_object->setup.sw_pos_6 = false;
  }
  if (microswitches & SW_POS_5) {
    node_object->setup.sw_pos_5 = true;
  } else {
    node_object->setup.sw_pos_5 = false;
  }
  if (microswitches & SW_POS_4) {
    node_object->setup.sw_pos_4 = true;
  } else {
    node_object->setup.sw_pos_4 = false;
  }
  if (microswitches & SW_POS_3) {
    node_object->setup.sw_pos_3 = true;
  } else {
    node_object->setup.sw_pos_3 = false;
  }
  if (microswitches & SW_POS_2) {
    node_object->setup.sw_pos_2 = true;
  } else {
    node_object->setup.sw_pos_2 = false;
  }
  if (microswitches & SW_POS_1) {
    node_object->setup.sw_pos_1 = true;
  } else {
    node_object->setup.sw_pos_1 = false;
  }
  // no sensors:
  //node_object->setup.sw_pos_8 = true;
}

int counterInit(){
    return 0;
}

void counterUpdate(node_object_t *handle)
{
    ++handle->data.counter;
}

/*
void hardwareProbeOPCN3(node_object_t *handle);
void hardwareProbeADS1115(node_object_t *handle);
void hardwareProbeSPS30(node_object_t *handle);
void hardwareProbeSHT40(node_object_t *handle);
void hardwareProbeSCD40(node_object_t *handle);
void hardwareProbeSGP41(node_object_t *handle);
*/
  
void hardwareInitInbuilt(node_object_t *handle) {
    handle->probes.counter = true;
    handle->probes.board_voltages = true;
    handle->data.counter = 0;
    hardwareBoardInit();
};

#include "sensirion-scd4x.h" 
void hardwareProbeSensors(node_object_t *handle) {
  probeBME280(handle);
  //probeOPCN3(handle);
  probeADS1115(handle);
  probeSPS30(handle);
  //probeGPS();
  //hardwareProbeSHT40(handle);
  //hardwareProbeSCD40(handle);
  //hardwareProbeSGP41(handle);
  Serial.println("SCD4X setup:");
  //setup_stuff();
  probeSDC4X(handle);
}

void hardwareInit(node_object_t *handle) {
    hardwareInitInbuilt(handle);
    hardwareEnable5V();
    //delay(100);
    hardwareProbeSensors(handle);
}

void hardwareUpdateData(node_object_t *handle) {
    counterUpdate(&node_object);
    hardwareBoardUpdate(&node_object);

    if (handle->probes.SPS30_present) {
        sps30Update(&node_object);
        //delay(4000);
        //sps30Update(&node_object);
    }
    if (handle->probes.BME280_present) {
        bme280Update(&node_object);
    }
    //if (handle->probes.OPCN3_present) {
    //    opcn3ReadFlush();
    //    delay(OPC_N3_SAMPLING_TIME); 
    //    opcn3ReadAll(&node_object);
    //    delay(100);
    //}
    if (handle->probes.ADS1115_1_present) {
        socketsUpdate(&node_object, ADS1115_1);
    }
    if (handle->probes.ADS1115_2_present) {
        socketsUpdate(&node_object, ADS1115_2);
    }
    if (handle->probes.SCD4X_present) {
      sdc4xUpdate(handle);
    }
}

// no sensors
void hardwareUpdateData_DUMMY(node_object_t *handle) {
  counterUpdate(&node_object);
  handle->probes.counter=true;
  //hardwareBoardUpdate(&node_object);

  //sps30
  handle->probes.SPS30_present=true;
  handle->data.sps30_PM1=random(0,2000);
  handle->data.sps30_PM2=random(0,2000);
  handle->data.sps30_PM4=random(0,2000);
  handle->data.sps30_PM10=random(0,2000);
  handle->data.sps30_NumPM0=random(0,2000);
  handle->data.sps30_NumPM1=random(0,2000);
  handle->data.sps30_NumPM2=random(0,2000);
  handle->data.sps30_NumPM4=random(0,2000);
  handle->data.sps30_NumPM10=random(0,2000);
  handle->data.sps30_PartSize=random(0,2000);
  //bme280
  handle->probes.BME280_present = true;
  handle->data.bme280_t=random(0,20000);
  handle->data.bme280_p=random(900000,1000000);
  handle->data.bme280_h=random(0,100000);
  //opcn3
  handle->probes.OPCN3_present = true;
  handle->data.opcn3_PM1=random(0,2000);
  handle->data.opcn3_PM2_5=random(0,2000);
  handle->data.opcn3_PM10=random(0,2000);
  // opcn3hist
  handle->probes.OPCN3_send_hist=true;
  handle->data.opcn3_bin0=random(0,50);
  handle->data.opcn3_bin1=random(0,50);
  handle->data.opcn3_bin2=random(0,50);
  handle->data.opcn3_bin3=random(0,50);
  handle->data.opcn3_bin4=random(0,50);
  handle->data.opcn3_bin5=random(0,50);
  handle->data.opcn3_bin6=random(0,50);
  handle->data.opcn3_bin7=random(0,50);
  handle->data.opcn3_bin8=random(0,50);
  handle->data.opcn3_bin9=random(0,50);
  handle->data.opcn3_bin10=random(0,50);
  handle->data.opcn3_bin11=random(0,50);
  handle->data.opcn3_bin12=random(0,50);
  handle->data.opcn3_bin13=random(0,50);
  handle->data.opcn3_bin14=random(0,50);
  handle->data.opcn3_bin15=random(0,50);
  handle->data.opcn3_bin16=random(0,50);
  handle->data.opcn3_bin17=random(0,50);
  handle->data.opcn3_bin18=random(0,50);
  handle->data.opcn3_bin19=random(0,50);
  handle->data.opcn3_bin20=random(0,50);
  handle->data.opcn3_bin21=random(0,50);
  handle->data.opcn3_bin22=random(0,50);
  handle->data.opcn3_bin23=random(0,50);

  handle->data.opcn3_bin1_MToF=random(0,10);
  handle->data.opcn3_bin3_MToF=random(0,10);
  handle->data.opcn3_bin5_MToF=random(0,10);
  handle->data.opcn3_bin7_MToF=random(0,10);

  handle->data.opcn3_sampling_p=random(0,10);
  handle->data.opcn3_flow_rate=random(0,10);
  handle->data.opcn3_t=random(0,10);
  handle->data.opcn3_h=random(0,10);
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
